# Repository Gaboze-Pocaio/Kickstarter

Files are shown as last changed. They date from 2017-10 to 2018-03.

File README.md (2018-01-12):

# Game Boy Zero

> Looking for a no frills multi system emulator that fits in your pocket? Look no further! This is it, Gameboy Zero - Handheld Edition!!!
>
> This project is a collaboration between  [moosepr](https://github.com/moosepr/) and  [32teeth](https://github.com/32teeth)
>
> We are **live** on [KickStarter](https://www.kickstarter.com/projects/sparky/gameboy-zero-handheld-edition)
>
> **Thank you everyone for your support.**





## Introduction

### Gameboy Zero - Handheld Edition
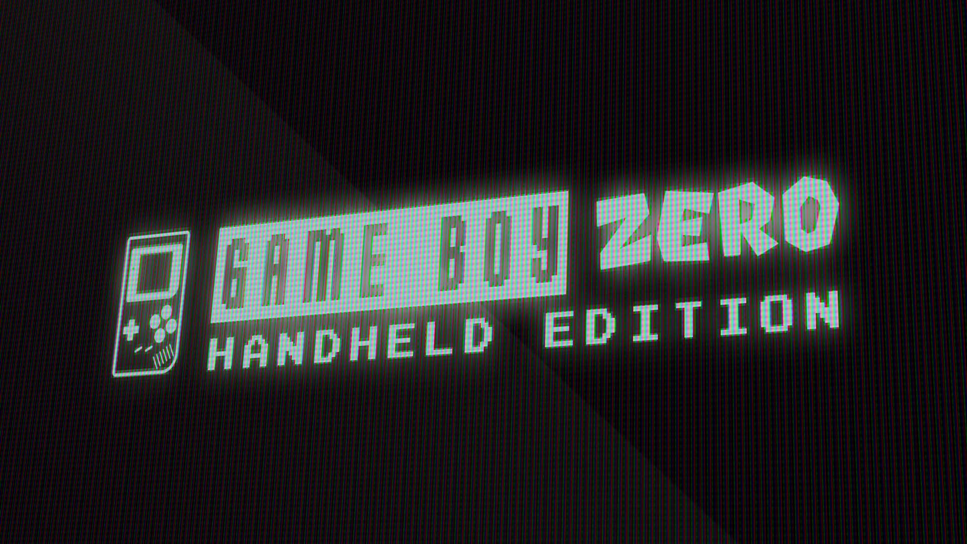
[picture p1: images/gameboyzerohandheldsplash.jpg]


Raspberry Pi Zero based arcade in you pocket

### Features:

* 2.8" TFT LCD
* Gameboy button layout interface
* Raspberry Pi Zero
* Battery Charger
* Shoulder / Trigger buttons
* 60 frames per second display

### Platforms:

The boards have been tested with the following platforms:

- [x] [Emulation Station](http://www.emulationstation.org/)
- [ ] [Lakka](http://www.lakka.tv/)
- [x] [RetroPie](https://retropie.org.uk/)

Other platforms are yet to be tested.

#### Eagle CAD Library

With our project we have included a few custom Eagle CAD Libraries

* [Displays](/library/GameboyZeroHandheldDisplays.lbr)
* [Raspberry Pi Zero](/library/RPI-Zero.lbr)

#### 3D Render
* [white board with parts](https://32teeth.github.io/Gameboy-Zero-Kickstarter/?parts)
* [black board no parts](https://32teeth.github.io/Gameboy-Zero-Kickstarter/?board)
* [holiday express no parts](https://32teeth.github.io/Gameboy-Zero-Kickstarter/?holiday)

## Details

| Version | Top | Bottom |
| --- | --- | --- |
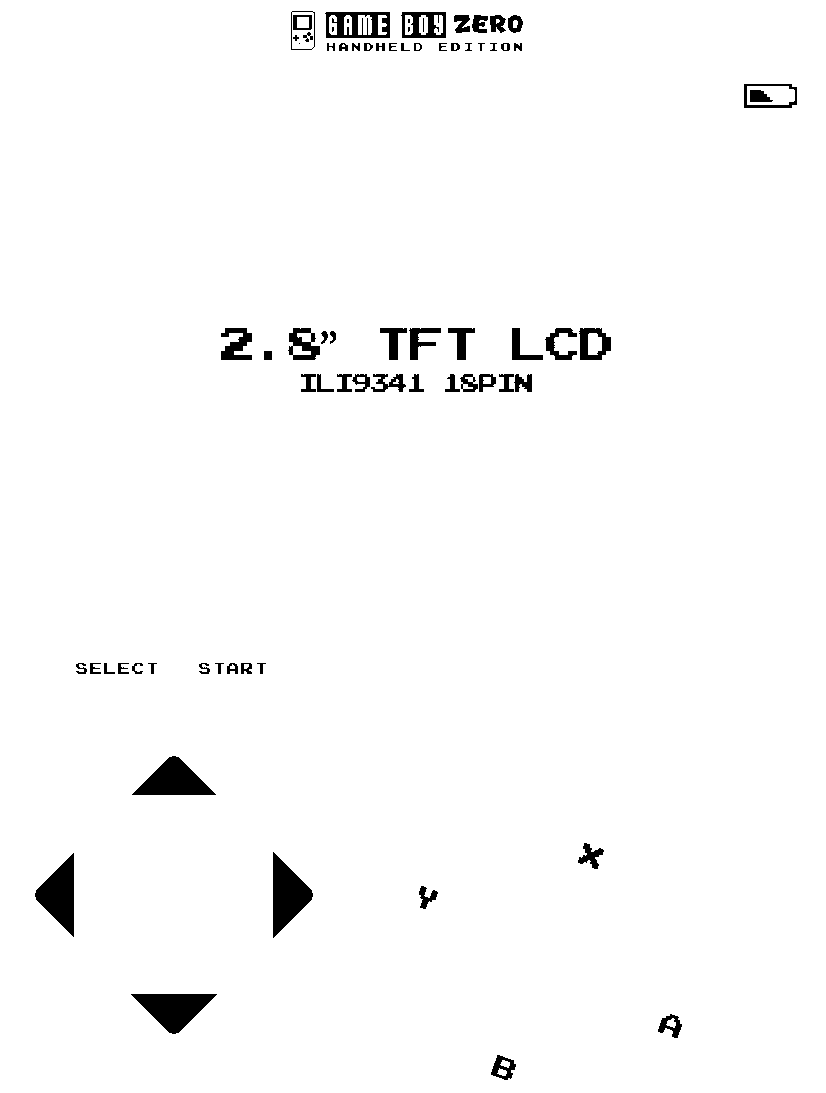
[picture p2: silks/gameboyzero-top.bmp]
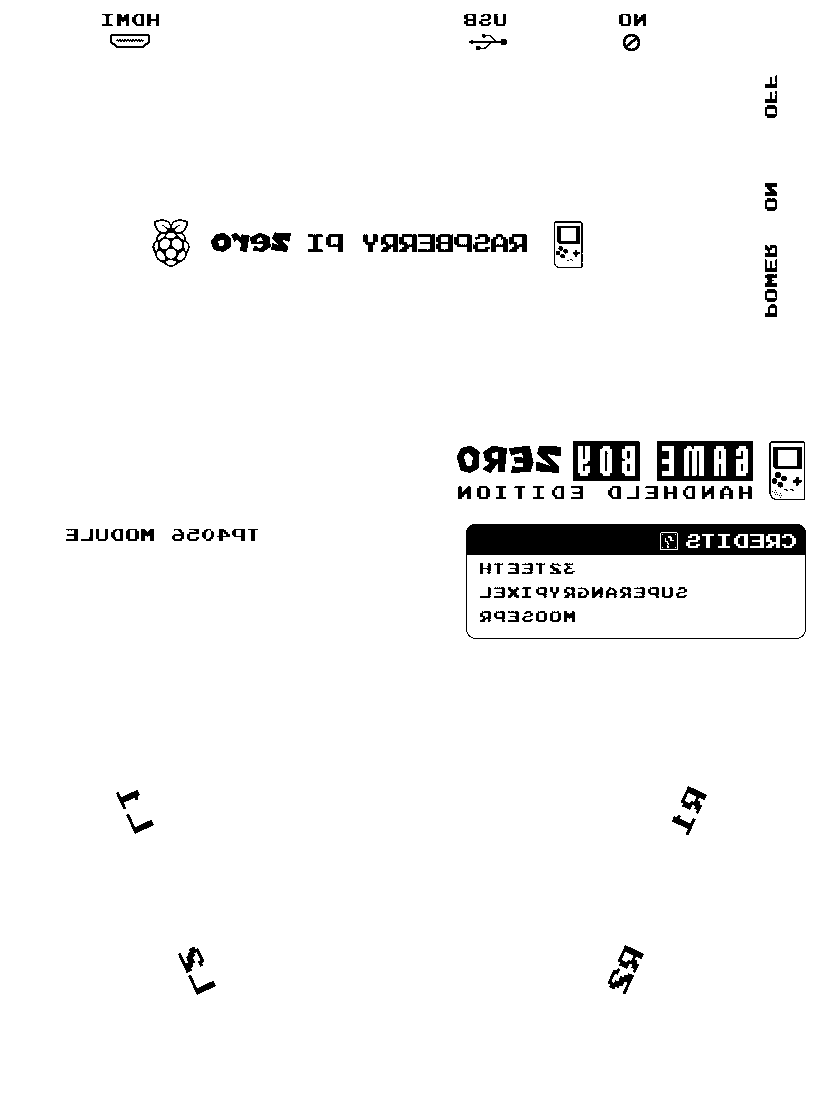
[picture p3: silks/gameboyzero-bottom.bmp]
| Flat Screen |  |  |
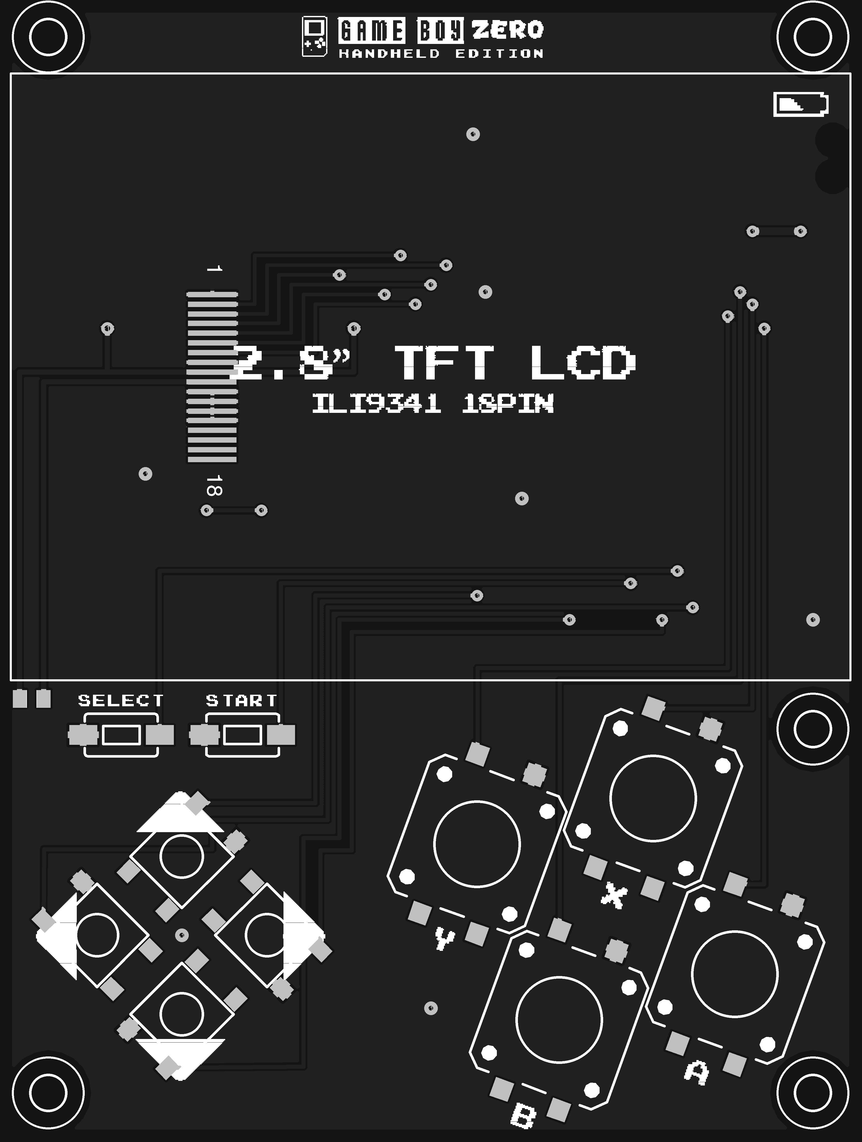
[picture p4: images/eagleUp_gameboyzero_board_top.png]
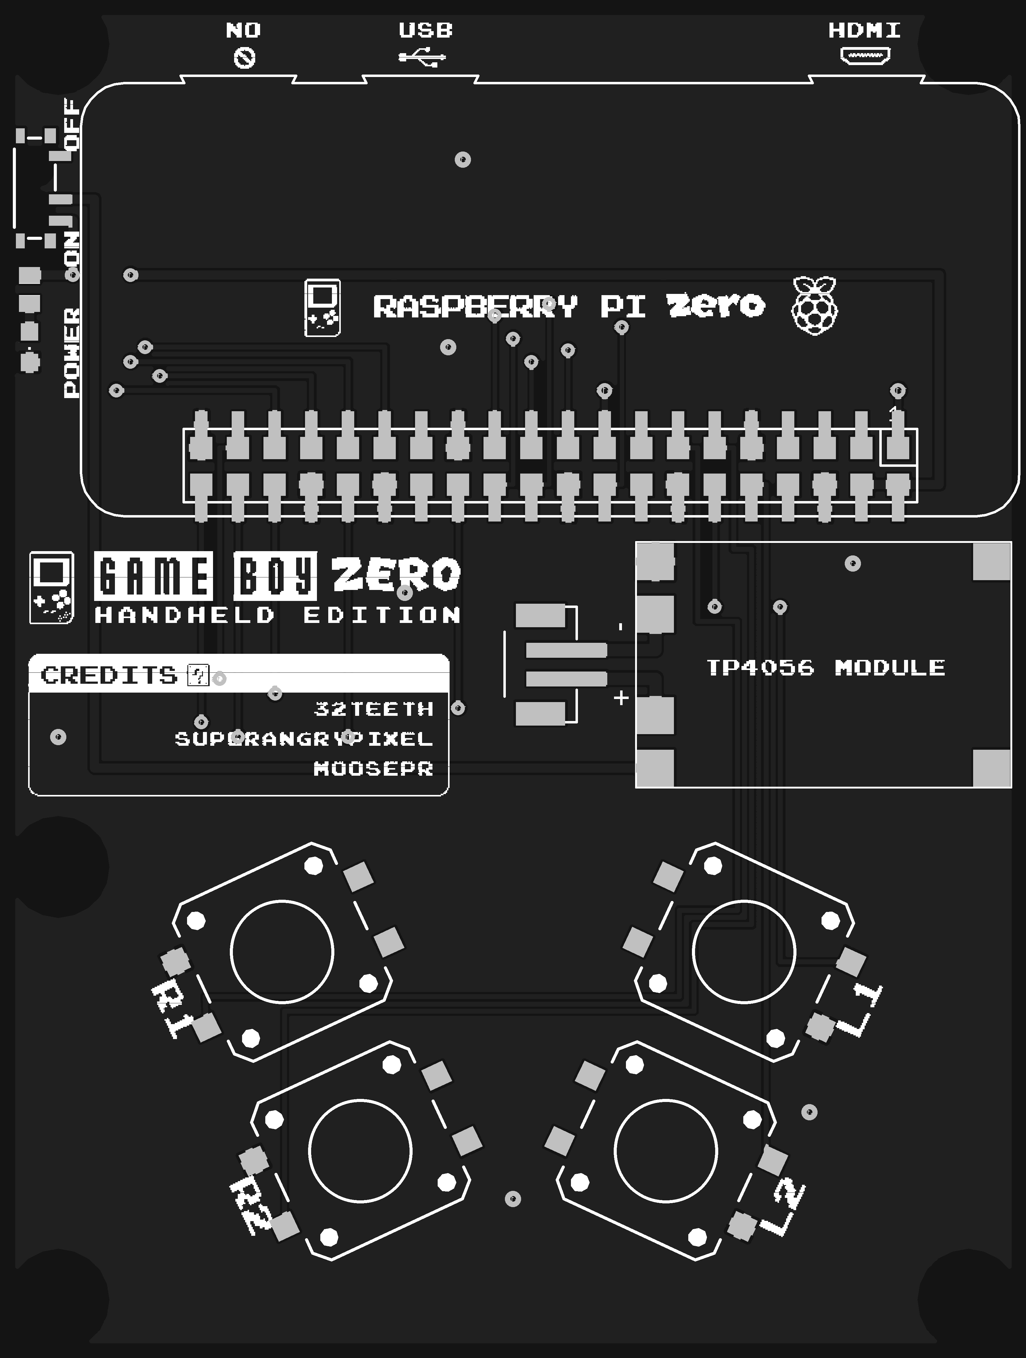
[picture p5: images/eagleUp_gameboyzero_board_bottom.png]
| Composite Board |  |  |
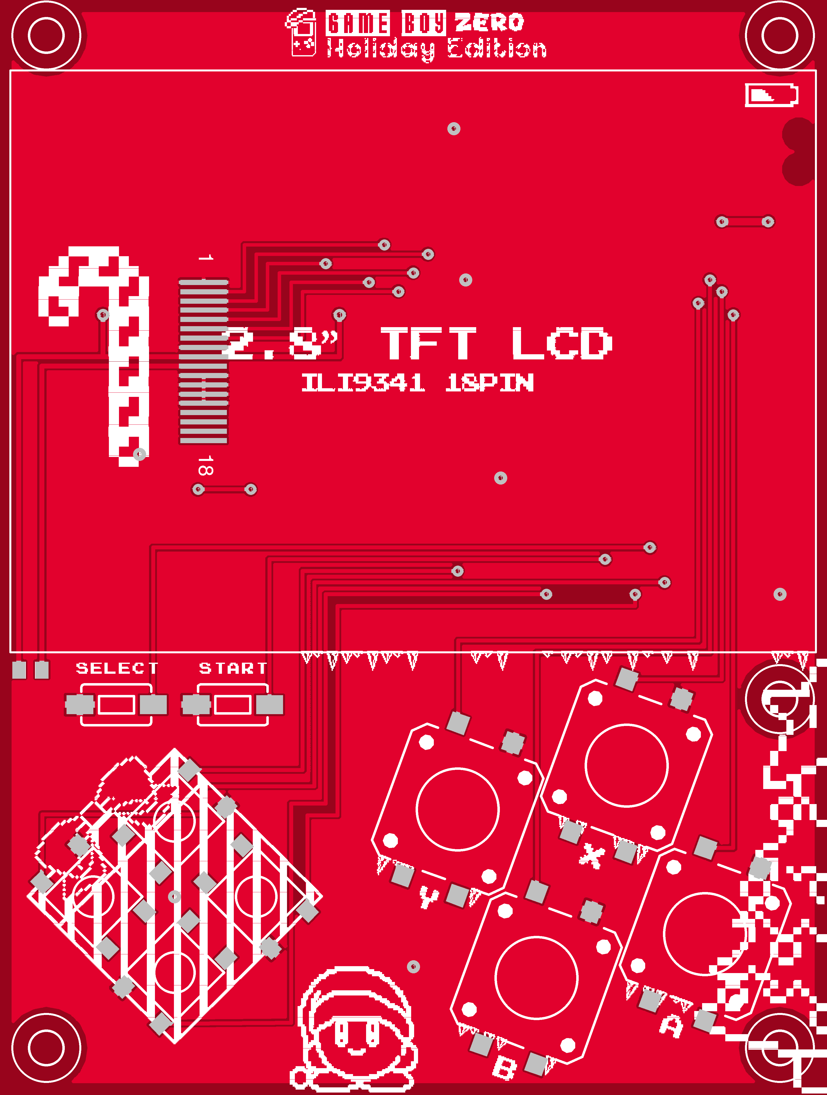
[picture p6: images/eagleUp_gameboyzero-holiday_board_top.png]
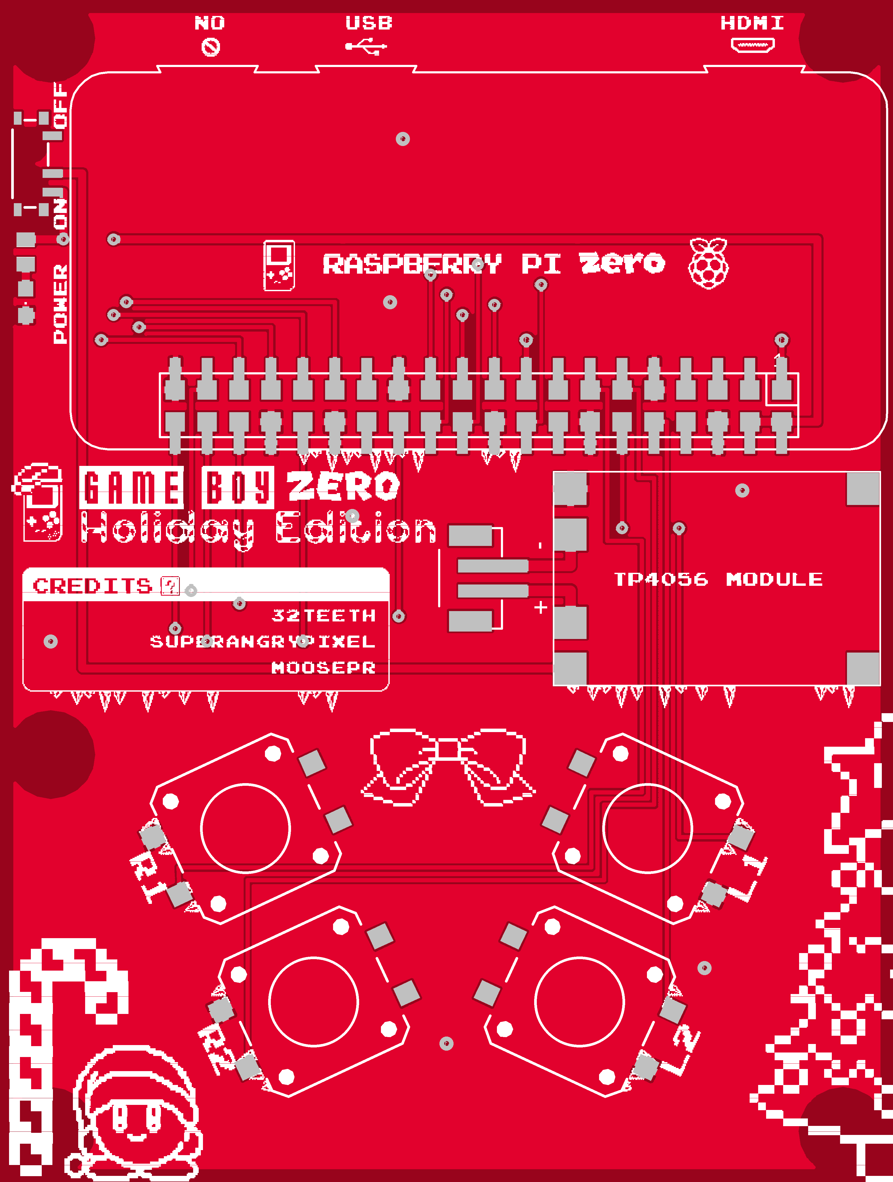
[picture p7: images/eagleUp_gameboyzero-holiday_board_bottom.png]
| Holiday Express Board |  |  |

## Custom Silk Screen

if you plan on changin the silk design,
* use the [gameboyzero sketch](design/gameboyzero) file
* all fonts required are in the  [fonts folder](fonts/)
* export artboard (with either 'TOP' or 'BOTTOM' group active as JPG)

*converting jpg to 2 color bitmap*
```shell
# imagemagick is required brew package
$ brew install imagemagick

# convert (replace with your file names and outputs)
# ex: convert "gameboyzero-top.jpg" -depth 1 -monochrome -colors 2 "gameboyzero-top.bmp"
$ convert "[jpg to convert]" -depth 1 -monochrome -colors 2 "[bmp to output]"
```

#### Import bmp in Eagle CAD.

* File > Import > Bitmap
* Select your bitmap
* Select **only** black color
* Change scale type to *mm*
* Change scale to ***0.086** (disregard the scale in the images)*
* Place it on layer layer 21 (tPlace) or 22 (bPlace)

| Top | Bottom |
| --- | --- |
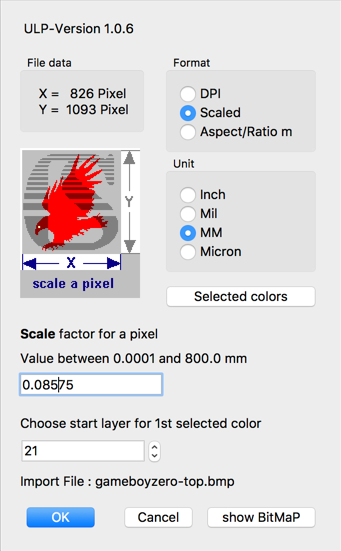
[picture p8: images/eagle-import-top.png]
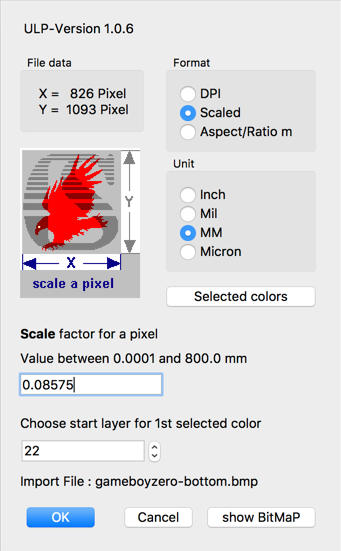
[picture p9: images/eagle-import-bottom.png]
|  |  |

## Plexi Case

The design for the layered plexi case are in the [case folder](/case)

*It consists of 5 layers:*
* TOP (optional for screen protection)
* SCREEN (fits over 2.8" TFT LCD)
* PI ZERO (fits around the Raspberry Pi Zero and TF4056 Module)
* BOTTOM (fits on top of the Raspberry Pi Zero)
* BATTERY (this is the layer to hold the LiPo battery in place)

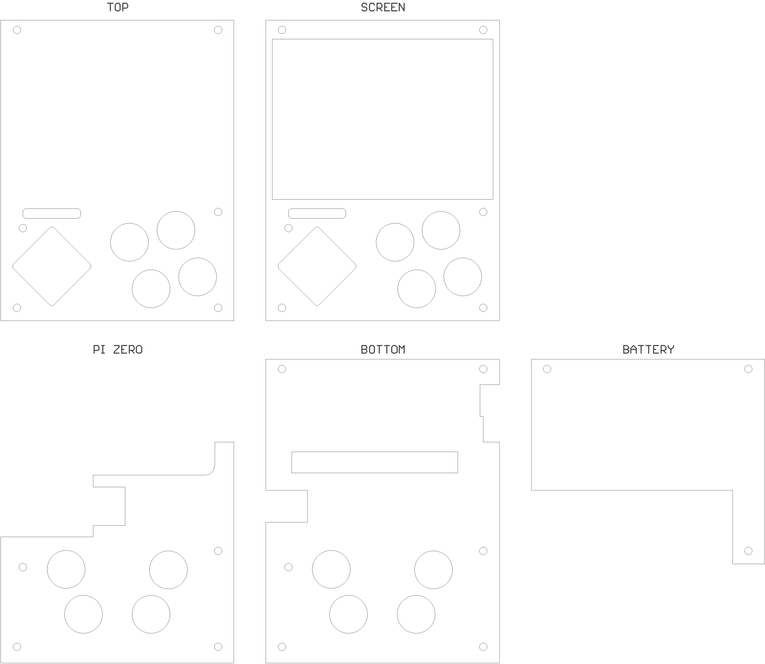
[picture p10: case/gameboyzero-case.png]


## Custom Config

> If you do not plan on using the provided Raspberry Pi image, simply [download](https://retropie.org.uk/download/) the latest RetroPie pre made image for the Raspberry Pi Zero

Once you have installed RetroPie onto your SD card and mounted it on your Pi follow along with the [Installation Instructions](INSTALL.md) document provided

#### A word from our sponsor

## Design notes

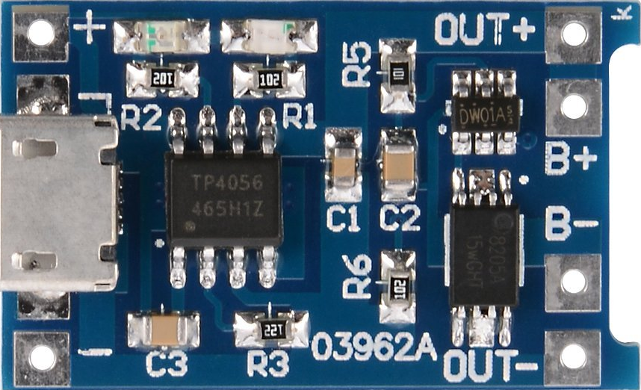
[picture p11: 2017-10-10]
docs/assets/gameboyzero-split-board/__auto_37.png

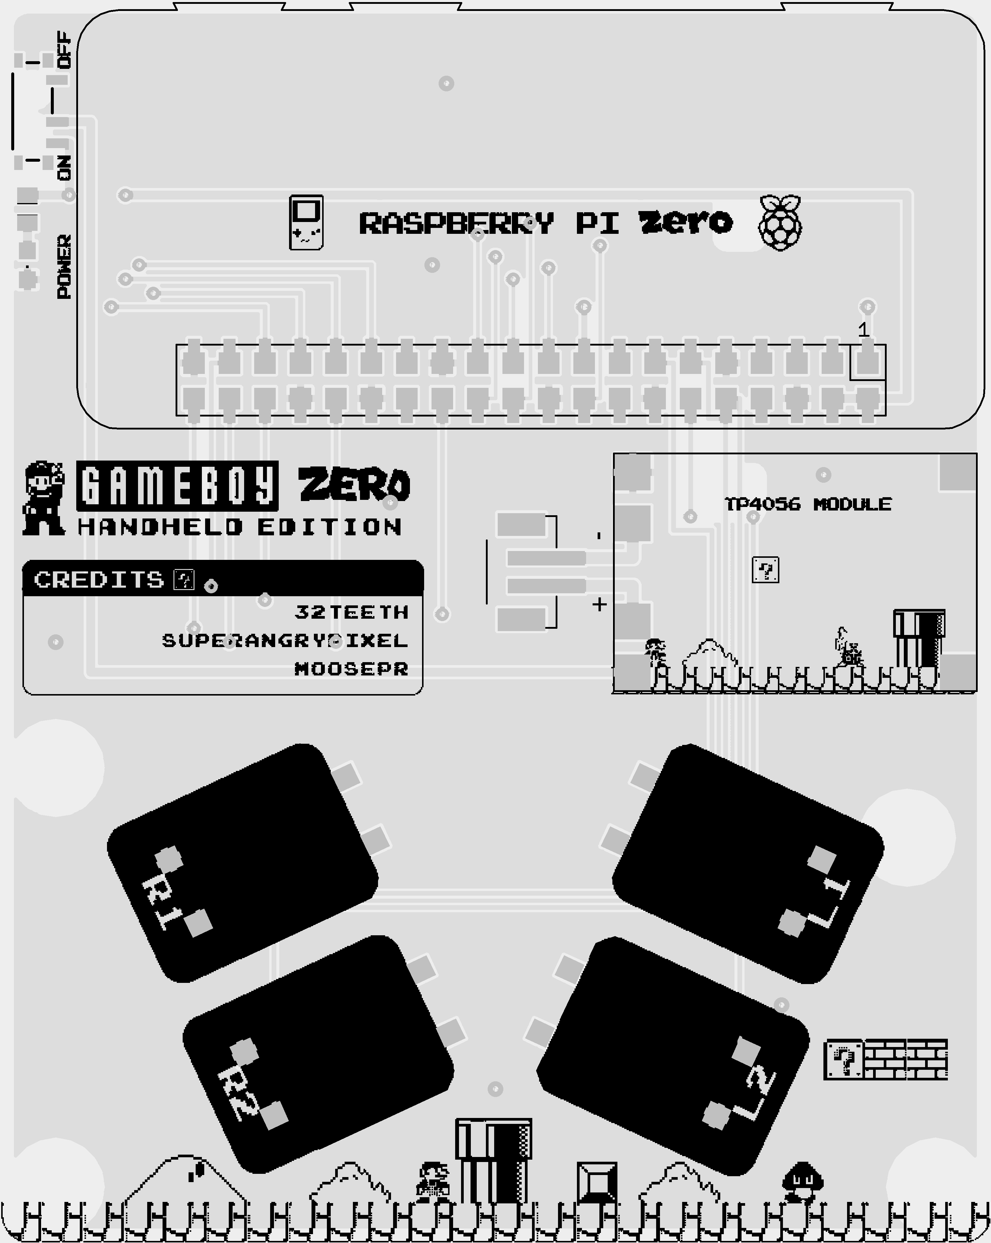
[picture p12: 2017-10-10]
docs/assets/gameboy/eagleUp_GBZH-2.8-JOY_bottom_board.png

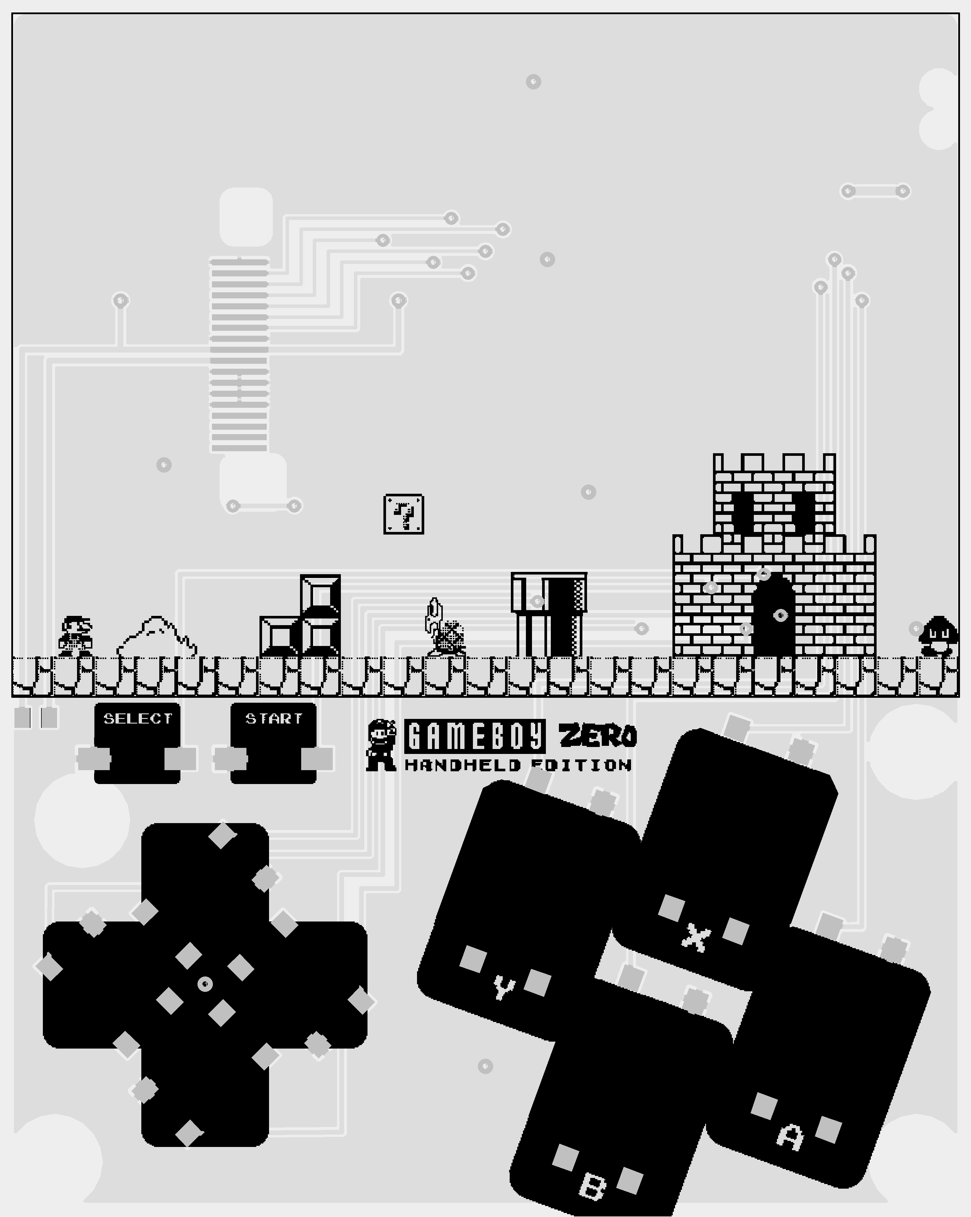
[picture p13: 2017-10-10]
docs/assets/gameboy/eagleUp_GBZH-2.8-JOY_top_board.png

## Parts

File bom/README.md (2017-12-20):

[Digi-Key Cart](http://www.digikey.com/short/qqrv9p)

**Not including** [TP4056 Charging Module](https://www.aliexpress.com/item/1-a-lithium-battery-charging-and-protect-one-plate-protection-2-in-1-18650-lithium-battery/1494965903.html) & [2.8" LCD Screen](https://www.aliexpress.com/item/2-8-inch-TFT-screen-4-wire-SPI-240-320-color-display-panel-ILI9341-drive-18/32797875095.html)

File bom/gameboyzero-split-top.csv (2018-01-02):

Designator | Manufacturer Part Number | Quantity
J2 | https://www.digikey.ca/product-detail/en/sullins-connector-solutions/PEC06SAAN/S1012E-06-ND/859159 | 1
CN1 | https://www.digikey.ca/product-detail/en/jst-sales-america-inc/S2B-PH-SM4-TB(LF)(SN)/455-1749-1-ND/926846 | 1
LED1 | https://www.digikey.ca/product-detail/en/lite-on-inc/LTST-C191KRKT/160-1447-1-ND/386836 | 1
S2 | https://www.digikey.ca/product-detail/en/apem-inc/MA12RTR/679-1847-1-ND/1973774 | 1
R1 | https://www.digikey.ca/product-detail/en/stackpole-electronics-inc/RMCF0805FT3R90/RMCF0805FT3R90CT-ND/2418397 | 1
R2 | https://www.digikey.ca/product-detail/en/yageo/RC0805JR-071KL/311-1.0KARCT-ND/731165 | 1
SCREEN1 | https://www.aliexpress.com/item/2-8-inch-TFT-screen-4-wire-SPI-240-320-color-display-panel-ILI9341-drive-18/32843525653.html | 1
BTN_A, BTN_B, BTN_X, BTN_Y | https://www.digikey.ca/product-detail/en/e-switch/TL3300DF160Q/EG4906CT-ND/2498468 | 4
BTN_SELECT, BTN_START | https://www.digikey.ca/product-detail/en/cts-electrocomponents/222BMVBAR/CT3090CT-ND/5227996 | 2
BTN_DOWN, BTN_LEFT, BTN_RIGHT, BTN_UP | https://www.digikey.ca/product-detail/en/c-k/PTS645SM43SMTR92-LFS/CKN9112CT-ND/1146934 | 4
POWER1 | https://www.aliexpress.com/item/1-a-lithium-battery-charging-and-protect-one-plate-protection-2-in-1-18650-lithium-battery/1494965903.html | 1
PI1 | https://www.digikey.ca/product-detail/en/Amphenol+FCI/95157-440LF/609-3124-ND/1824561 | 1

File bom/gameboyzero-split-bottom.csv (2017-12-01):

Designator | Manufacturer Part Number | Quantity
J3 | https://www.digikey.ca/product-detail/en/sullins-connector-solutions/PPTC061LFBN-RC/S7004-ND/810145 | 1
LED2 | https://www.digikey.ca/product-detail/en/lite-on-inc/LTST-C191KRKT/160-1447-1-ND/386836 | 1
R3 | https://www.digikey.ca/product-detail/en/yageo/RC0805JR-071KL/311-1.0KARCT-ND/731165 | 1
BTN_L1, BTN_L2, BTN_R1, BTN_R2 | https://www.digikey.ca/product-detail/en/e-switch/TL3300DF160Q/EG4906CT-ND/2498468 | 4

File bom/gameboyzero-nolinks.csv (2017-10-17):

Designator | Manufacturer Part Number | Quantity
CN1 | S2B-PH-SM4-TB(LF)(SN) | 1
LED1 | LTST-C191KRKT | 1
S2 | MA12R | 1
R1, R2 | RMCF0805JT100R | 2
SCREEN1 | see link for screen | 1
BTN_A, BTN_B, BTN_L1, BTN_L2, BTN_R1, BTN_R2, BTN_X, BTN_Y | TL3300AF160Q | 8
BTN_SELECT, BTN_START | 222BMVBAR | 2
BTN_DOWN, BTN_LEFT, BTN_RIGHT, BTN_UP | TL3301SPF160QG | 4
POWER1 | see link for power | 1
PI1 | see link for smd header | 1

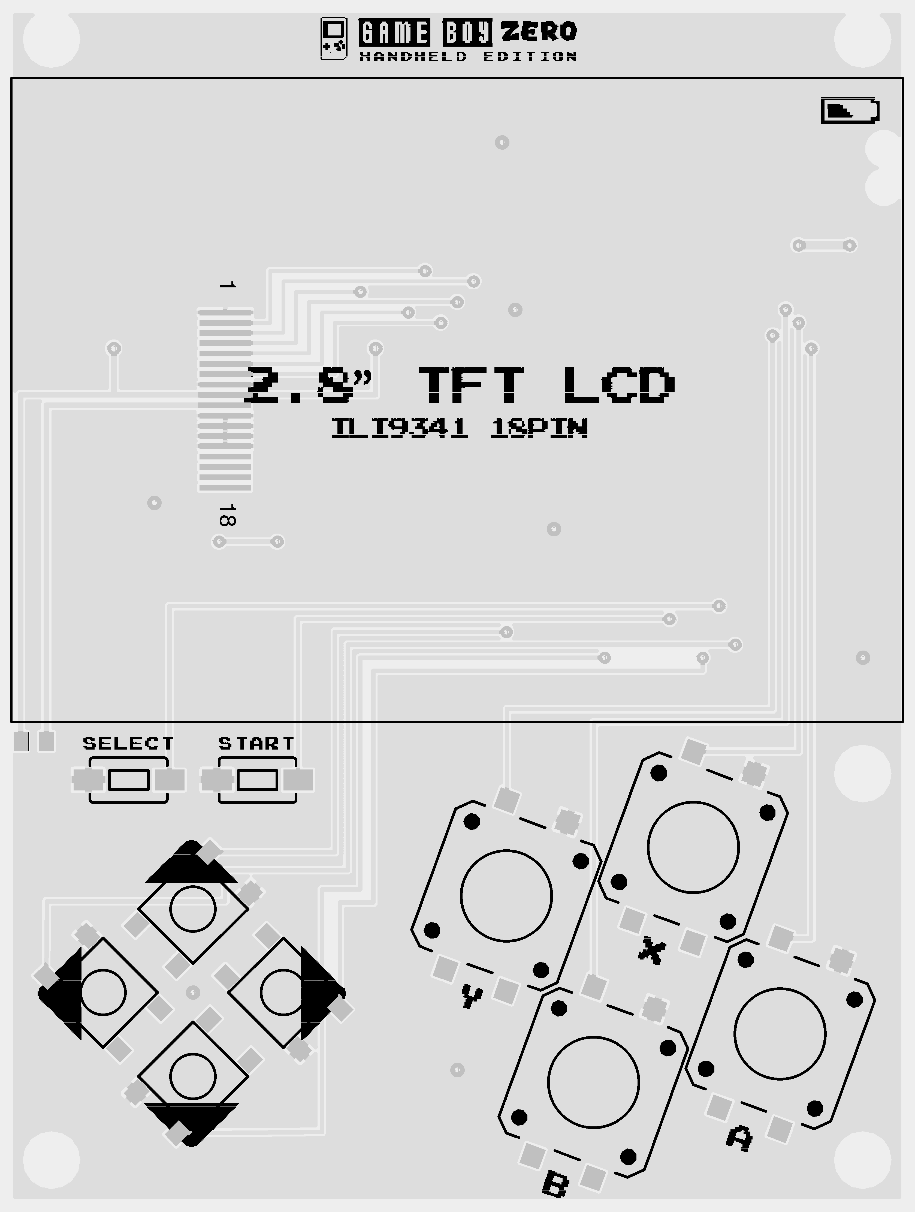
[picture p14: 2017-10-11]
docs/assets/gameboy-parts/eagleUp_gameboyzero_top_board.png

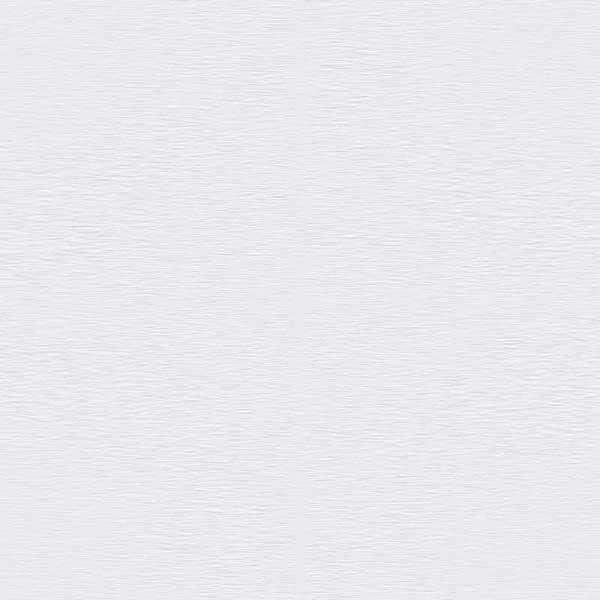
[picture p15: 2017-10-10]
docs/assets/gameboy-parts/Metal_Silver.jpg

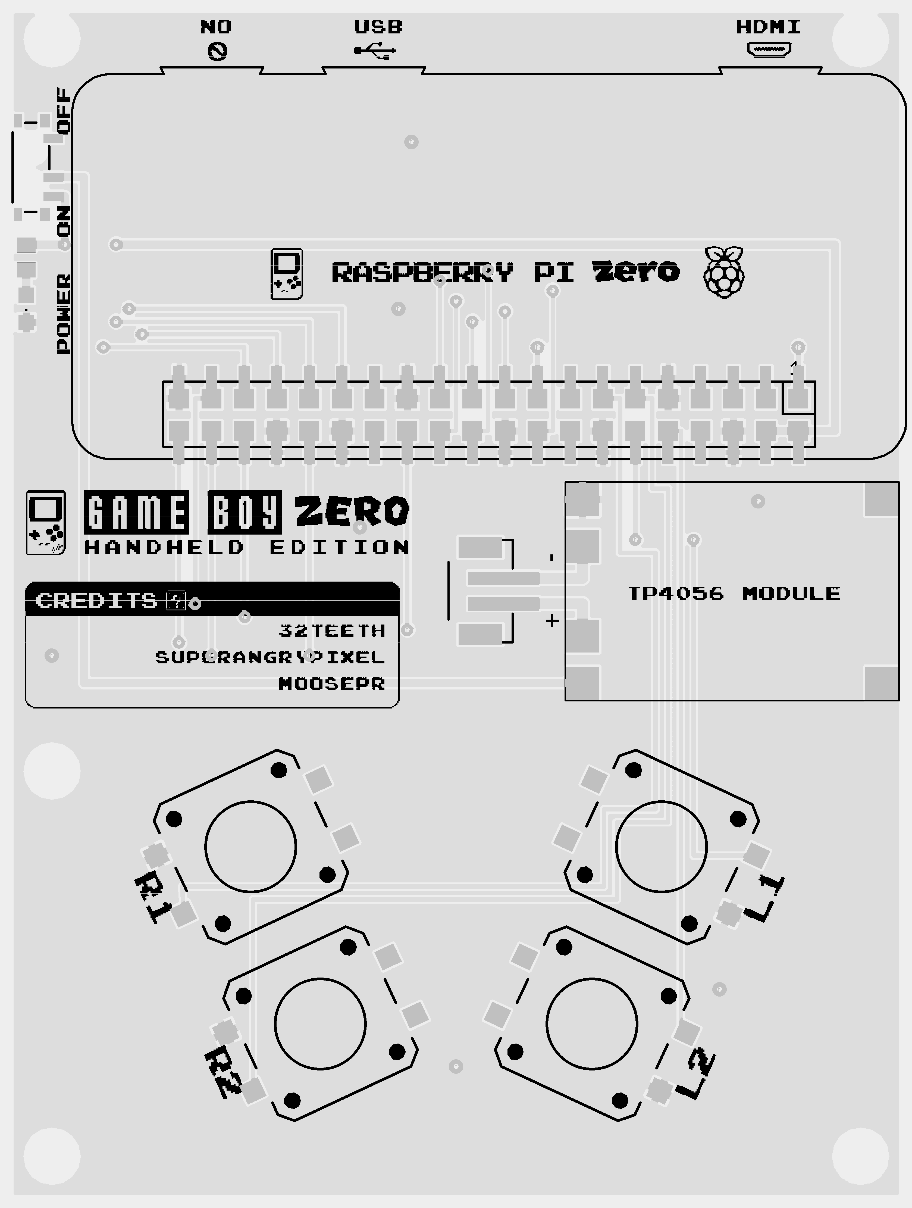
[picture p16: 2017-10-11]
docs/assets/gameboy-parts/eagleUp_gameboyzero_bottom_board.png

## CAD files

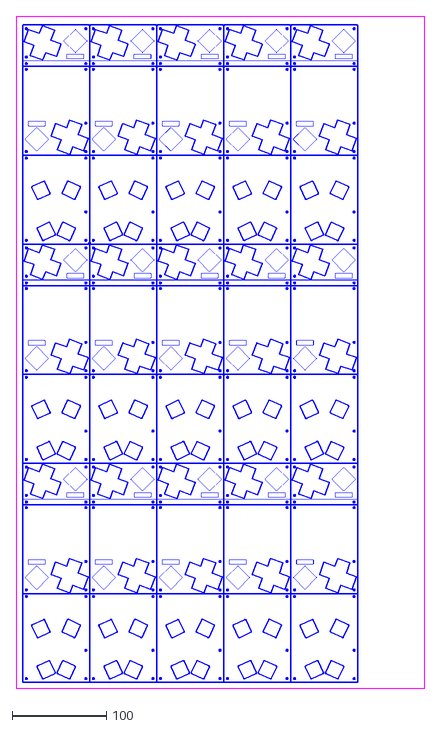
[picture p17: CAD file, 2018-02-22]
case/gameboyzero-split-board/gameboyzero-split-board-single.dxf
432.1 x 711.5

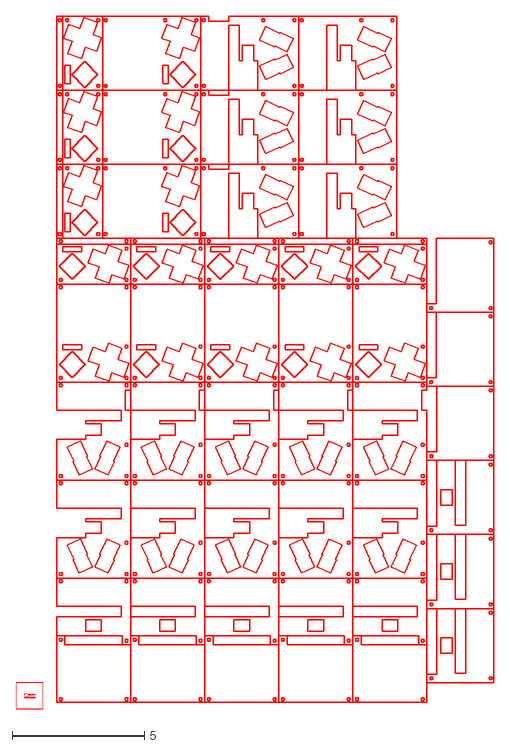
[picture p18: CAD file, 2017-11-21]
case/gameboyzero/gameboyzero.dxf
18.0 x 26.2

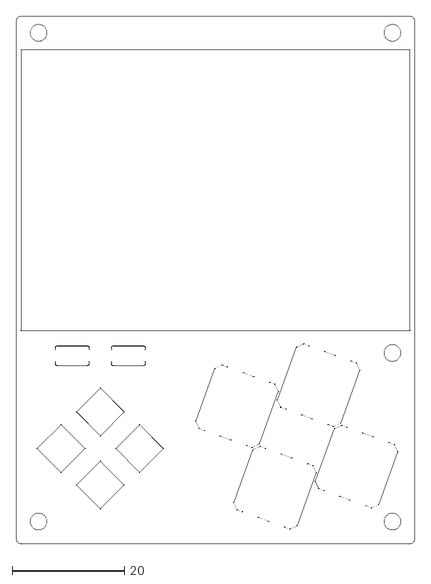
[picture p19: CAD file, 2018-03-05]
eagle/gameboyzero-split-board/gameboyzero-split-top.dxf
71.0 x 94.0

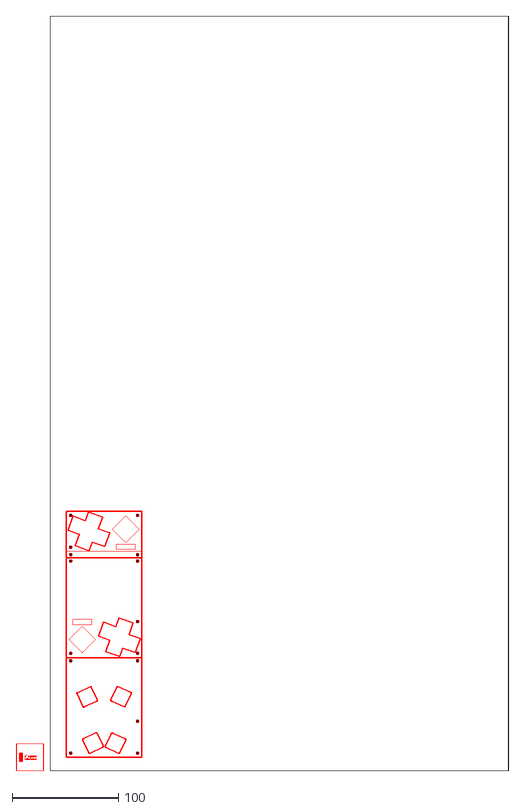
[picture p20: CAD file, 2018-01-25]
case/gameboyzero-split-board/gameboyzero-split-board.dxf
463.7 x 711.4

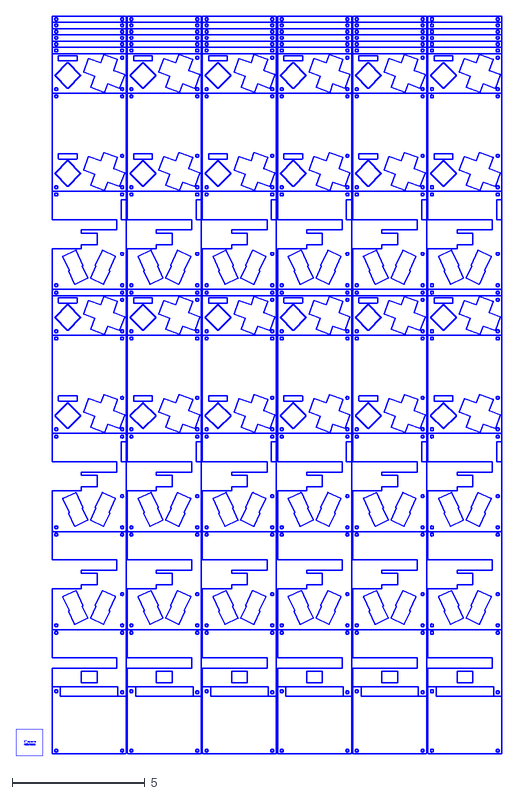
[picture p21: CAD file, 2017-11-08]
case/gameboyzero/gameboyzero-blue.dxf
18.3 x 27.9

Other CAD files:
sketchup/gameboyzero-holiday.skp
sketchup/gameboyzero-split-board.skp
sketchup/gameboyzero-split-board~.skp
sketchup/gameboyzero.skp

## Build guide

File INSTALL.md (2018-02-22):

# Gameboy Zero - Handheld Edition Installation

> This document is intended for a somewhat advanced user base, but we have made it simple enough to follow along for anyone

### Prerequisites

1. Fresh RetroPie install mounted on an SD Card
2. Raspberry Pi Zero *(preferably WiFi edition)*
3. Keyboard
4. OTG USB Cable (to plug in a USB A type keyboard)
5. Mini HDMI (you know, to see things on a screen)

## Step 1

> Setup Raspberry Pi requirements

With your Keyboard and HDMI cable plugged in, go ahead and turn on your Raspberry Pi Zero
Allow it to go through the boot requirements (RetroPie will reboot once on it's own)

Once the Raspberry Pi boots into RetroPie, it will start EmulationStation automatically.

You will see a screen telling you to either set up a controller or press F4 to exit.

* Press F4 to exit to terminal

### WiFi

Once the Raspberry Pi reboots into EmulationStation, use your keyboard and navigate to RetroPie configuration

Select WiFi and enter your SSID/PSK information as necessary

Once you have connected to your WiFi network, you can go back to your laptop and continue via SSH from there

#### Optional

Should you choose to work completely from terminal, hit F4 from the EmulationStation menu to get to terminal

```shell
sudo iwlist wlan0 scan
sudo nano /etc/wpa_supplicant/wpa_supplicant.conf
```

```shell
network={
  ssid="your ssid"
  psk="your password"
}
```

```shell
sudo systemctl daemon-reload
ifconfig wlan0
```

If you have done your WiFi correctly from here you can use SSH

```
ssh pi@[ip address]
```

### Config

* Run the Rapsberry Pi configuration program
```shell
sudo raspi-config
```
In the Interfaceing Options menu, you will need to 
1. Enable SSH
2. Enable SPI

In the Advance Options menu, you will need to
1. Expand Filesystem
2. Disable Overscan

Once these are complete, you will be asked to reboot you Raspbery Pi.
Do so.

## Step 2

> We will now be connecting the 2.8" ILI9341 TFT LCD module, so you can set your other keyboard aside for now

From you computer *(not the Raspberry Pi)*

### TFT Device

Enter the following to add a Loadable Kernel Module for the TFT Device
```shell
sudo modprobe fbtft_device custom name=fb_ili9341 gpios=reset:25,dc:24 speed=80000000 fps=60 bgr=1 rotate=90
```

Confirm the module has been loaded

```shell
dmesg | tail 
```

See the TFT LCD module details
```shell
fbset -fb /dev/fb1
```

Lets test that we can show 'stuff' on the TFT LCD module (this will simply add static noise)
```shell
cat /dev/urandom > /dev/fb1
```

Map the console to the TFT LCD Module
*you should now see a scaled terminal window on the TFT*
```shell
con2fbmap 1 1
```

Should you ever need to stop the mapping, reverse the command
```shell
# switch tft to hdmi
con2fbmap 1 0
```

*Note:* if you need to remove the module, simply

```shell
sudo modprobe -r fbtft_device
```

## Step 3

### Automate the above on startup

Open the modules file
```shell
sudo nano /etc/modules
```

Add these lines to the bottom
```shell
spi-bcm2835
fbtft_device
```

*Hit 'CTRL+X' and 'Y' to confirm the save*

### Create a configuration file for the TFT LCD Module

This will create an empty file named fbtft.conf
```shell
sudo nano /etc/modprobe.d/fbtft.conf
```

Add this line to the empty file
```shell
options fbtft_device custom name=fb_ili9341 gpios=reset:25,dc:24 speed=80000000 fps=60 bgr=1 rotate=90 custom=1
```

*Hit 'CTRL+X' and 'Y' to confirm the save*

### Installing the Framebuffer Copy tool

The following lines will download and install the Frambuffer Copy tool in a folder in the root directory

```shell
cd
sudo apt-get install cmake
git clone https://github.com/tasanakorn/rpi-fbcp fbcp
cd fbcp/
mkdir build
cd build/
cmake ..
make
sudo install fbcp /usr/local/bin/fbcp
fbcp
```

*Hit CTRL+C to exit 'fbcp'*

### Add Framebuffer Copy to our boot sequence
In order to have a command or program run when the Pi boots we will edit the 'rc.local' file

```shell
sudo nano /etc/rc.local
```

Add the following **just before** the ```exit 0``` line
```shell
fbcp&
```

*Hit 'CTRL+X' and 'Y' to confirm the save*

Your file *(if you have no other commands running)* will look something like this
```shell
### replace with this
_IP=$(hostname -I) || true
if [ "$_IP" ]; then
  printf "My IP address is %s\n" "$_IP"
fi

fbcp&

exit 0
```

## Step 5

> USB Audio Configuration

Plug in your USB Audio Card, and list your usb devices

```shell
lsusb
```

Now run the sound modules probe

```shell
cat /proc/asound/modules
```

You will see something like

```shell
 0 snd_bcm2835
 1 snd_usb_audio
```

The ```snd_bcm2835``` is the default, we wan't to force the USB output so, we will edit the conf file

```shell
sudo nano /etc/modprobe.d/alsa-base.conf
```

Add these lines

```shell
options snd_usb_audio index=0
options snd_bcm2835 index=1
options snd slots=snd-usb-audio,snd-bcm2835
```

Reboot, and return to terminal (F4) once EmulationStation has restarted

List out the module probe

```
cat /proc/asound/modules
```

You will see something like

```shell
 0 snd_usb_audio
 1 snd_bcm2835
```

Success, enjoy the sound

## Step 6

> Now we are ready to configure the GPIO on the Raspberry Pi as a controller

### Install RetroGame

```shell
cd
curl -O https://raw.githubusercontent.com/adafruit/Raspberry-Pi-Installer-Scripts/master/retrogame.sh
sudo bash retrogame.sh
```
When you run the retrogame.sh file, you will be presented with a menu.

Select the **PiGRRL 2 Controls** option, and the program will continue to install some modules.

Once complete, you will be asked if you want to reboot. 
#### Don't reboot just yet

## Step 7
> You will now be assigning keyboard inputs to action buttons of the controller (GPIO pins on the Raspberry Pi)

### RetroGame Configuration

Edit the RetroGame configuration file
```shell
sudo nano /boot/retrogame.cfg
```

You can replace the entire file with the following
* **pro tip**:Hit CTRL+K on you keyboard to delete lines*

```shell
# Here's a pin configuration for the PiGRRL 2 project:
LEFT      		22  # Joypad left
RIGHT     		20  # Joypad right
UP         		 7  # Joypad up
DOWN      		12  # Joypad down
LEFTCTRL  		19  # 'A' button
LEFTALT    		 5  # 'B' button
Z          		 6  # 'X' button
X         		13  # 'Y' button
RIGHTSHIFT      26  # 'Select' button
ENTER     		16  # 'Start' button
A         		18  # Left shoulder button
S         		27  # Right shoulder button
Q         		15  # Left trigger button
W         		17  # Right trigger button
ESC       		16 26  # Exit ROM; PiTFT Button 1
```

*Hit 'CTRL+X' and 'Y' to confirm the save*

### EmulationStation Input Configuration
> This is really just a visual check to ensure your file looks as below

Open the EmulationStation Input configuration file
```shell
sudo nano ~/.emulationstation/es_input.cfg
```

Ensure that your file's content are **exactly** as below
```xml
<?xml version="1.0"?>
<inputList>
  <inputAction type="onfinish">
    <command>/opt/retropie/supplementary/emulationstation/scripts/inputconfiguration.sh</command>
  </inputAction>
  <inputConfig type="keyboard" deviceName="Keyboard" deviceGUID="-1">
    <input name="pageup" type="key" id="97" value="1"/>
    <input name="start" type="key" id="13" value="1"/>
    <input name="up" type="key" id="1073741906" value="1"/>
    <input name="a" type="key" id="1073742048" value="1"/>
    <input name="b" type="key" id="1073742050" value="1"/>
    <input name="down" type="key" id="1073741905" value="1"/>
    <input name="pagedown" type="key" id="115" value="1"/>
    <input name="right" type="key" id="1073741903" value="1"/>
    <input name="x" type="key" id="122" value="1"/>
    <input name="select" type="key" id="1073742053" value="1"/>
    <input name="y" type="key" id="120" value="1"/>
    <input name="left" type="key" id="1073741904" value="1"/>
  </inputConfig>
</inputList>
```

If all is good as above, hit CTRL+X to exit the editor and

# Step 8
> The final reboot, you can now unplug the HDMI from the Raspberry Pi

```shell
sudo nano /boot/cmdline.txt
```

```shell
dwc_otg.lpm_enable=0 console=tty1 console=ttyAMA0,115200 root=/dev/mmcblk0p2 rootfstype=ext4 elevator=deadline rootwait fbcon=map:10 fbcon=font:6x12 logo.nologo
```

Reboot
```shell
sudo reboot now
```

RetroPie will reboot and start EmulationStation *(all on the tiny screen)*

Once EmulationStation is up, you will again see the 'No Device Configured' screen...  ...***Don't Panic***

With your keyboard plugged in, press and hold 'Enter' until the Controller Configuration shows up on the screen

Hit your keys on your keyboard as mapped above, skip the analog sticks
* **pro tip**: When you get to the section*

# Step 9
> This one is all on you

We **DO NOT** provide any system or game *'roms'*, for that you will need Google.

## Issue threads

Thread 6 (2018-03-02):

[3D Models] what's in the sketchup files ?

tobozo, 2018-03-02:
[EDIT] Found the 3D Models on a related repo although those seems to be for another model
- [Gameboy.stl](https://github.com/GameboyZero/GabozePocaio/blob/29c8e6133e9ad878d548ccbc102e7fb717bc6881/stl/Gameboy.stl)
- [GBPZ-top.stl](https://github.com/GameboyZero/GabozePocaio/blob/29c8e6133e9ad878d548ccbc102e7fb717bc6881/stl/GBPZ-top.stl)
- [GBPZ-bottom.stl](https://github.com/GameboyZero/GabozePocaio/blob/29c8e6133e9ad878d548ccbc102e7fb717bc6881/stl/GBPZ-bottom.stl)

got mine today from tindie \o/ unboxing went well and I was [looking for some 3d models](https://www.thingiverse.com/search?q=gameboy+zero) to print a Gameboy Zero case /w buttons, but it looks like the "Gameboy Zero" platform name is kinda generic and over used on thingiverse :sob:

I'm not sure if this is the right place to ask for this (already asked on tindie), but would any owner of a sketchup licence be kind enough to export the [sketchup files](https://github.com/32teeth/Gameboy-Zero-Kickstarter/tree/master/sketchup) into the non-proprietary STL format so github can display previews of what's in there?

https://extensions.sketchup.com/content/sketchup-stl

So far the [Blender importer](https://github.com/martijnberger/pyslapi) is the only solution I've found that doesn't require registration, but it requires versions of python and blender I don't use currently and can't upgrade without breaking my own scripts.

@32teeth if you're the lucky sketchup licence owner and author of these files, could you point me in the right direction, or eventually create a STL folder in this repo and populate it with the converted STL files?

tobozo, 2020-06-22:
closed by error or just not worth the answer?

Closed 2020-06-22.

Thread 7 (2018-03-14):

Back PCB can't mount to front if female headers are added to Pi Zero

albill, 2018-03-14:
If you put female headers on the underside of the Pi Zero (as the video shows as one of two options), the headers are so tall that they keep the back 4 button PCB from mating with its pins on the front PCB as the female headers make the distance too much.

tobozo, 2018-03-23:
you can still try this [workaround](https://twitter.com/TobozoTagada/status/970712510717419522)

32teeth, 2018-03-27:
Additionally you can use [Short Headers](https://www.adafruit.com/product/2243)

albill, 2018-04-06:
No, short headers turn out not to work (thought they're stuck on my zero now). The header pins that come pre-soldered are too long so even with short female headers, a mm or two of pin shows and the zero is moved far enough out that the two PCBs cannot be assembled flush.

My next step will be to gently trim a mm or two of of EACH pin, which is damn tedious when this all could have been avoided.

Did anyone even test this with headers before sending it out to Kickstarter backers or did you just test this by soldering the zero directly to the board?

tobozo, 2018-04-06:
Found this out too, now I've officially wasted two Pi Zeros by just attempting to replicate the mounting on the advertised product page, or by following @32teeth advices.

Closed 2020-06-22.

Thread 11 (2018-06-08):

Case .dxf files

mackemint, 2018-06-08:
Opening any of the .dxf-files under /case in Autodesk gives me the following error:
TranslationWorker-InternalFailure Unrecoverable exit code from extractor: -1073741831
AutoCAD-InvalidFile Sorry, the drawing file is invalid and cannot be viewed. - Please try to recover the file in AutoCAD, and upload it again to view.

Using other services produces similar error messages.

Closed 2020-06-22.

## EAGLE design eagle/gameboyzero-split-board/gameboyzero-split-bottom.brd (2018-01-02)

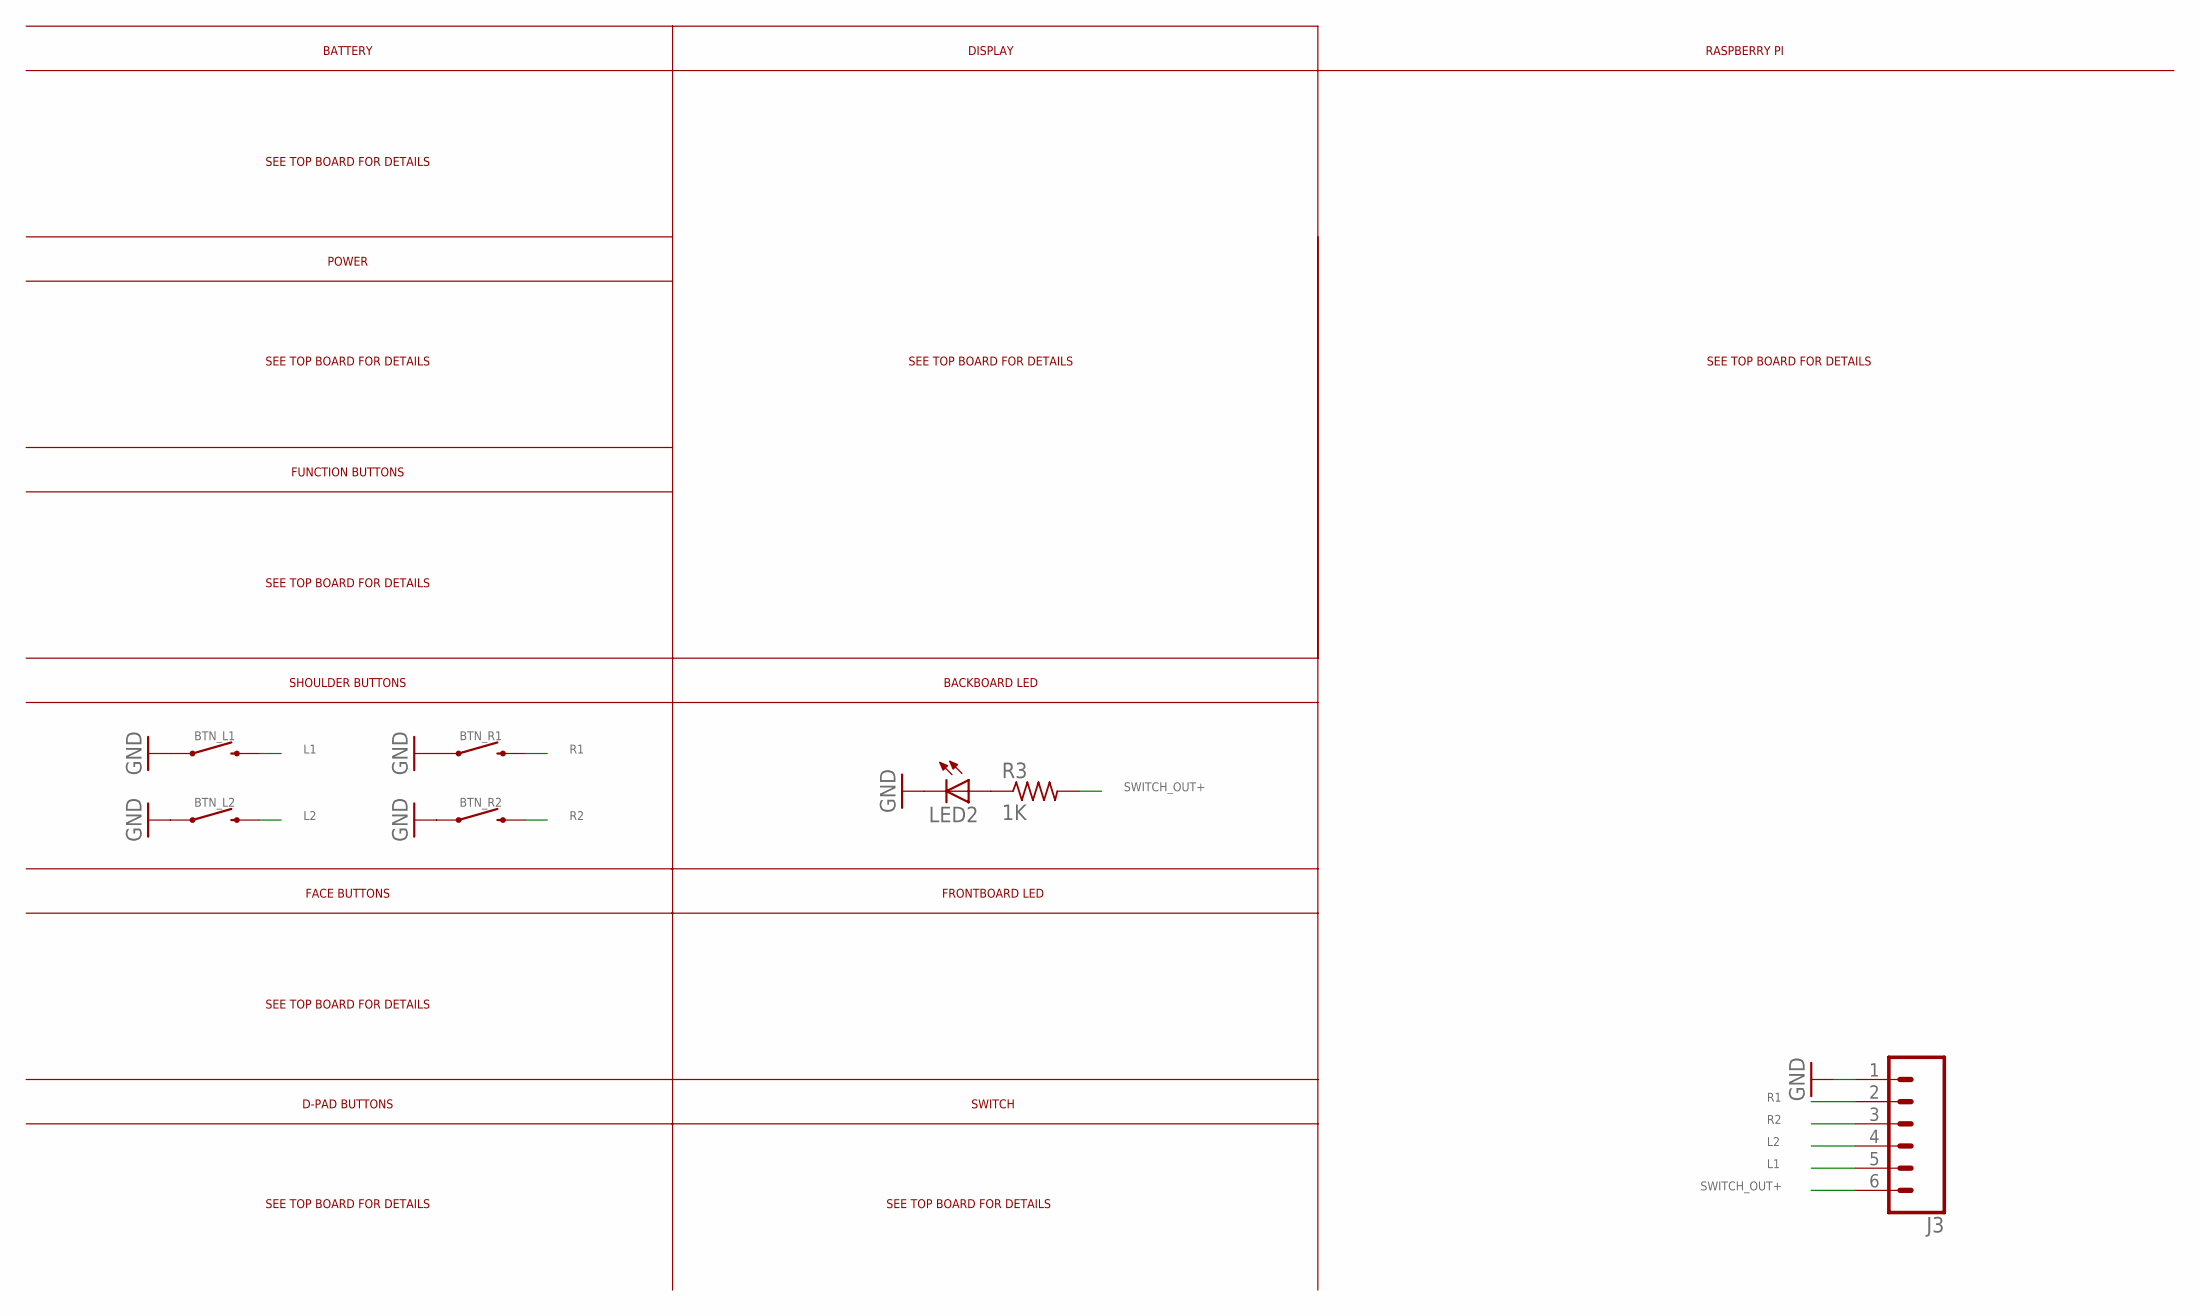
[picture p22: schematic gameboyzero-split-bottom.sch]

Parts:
BTN_L1, BTN_L2: MOMENTARY-SWITCH-SPST-SMD-12MM; TACTILE_SWITCH_SMD_12MM
BTN_R1, BTN_R2: MOMENTARY-SWITCH-SPST-SMD-12MM; TACTILE_SWITCH_SMD_12MM
J3: CONN_06SILK_FEMALE_PTH; 1X06
LED2: LEDCHIPLED_0805; CHIPLED_0805
R3: 1K; R0805

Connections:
GND: BTN_L1.1, BTN_L2.1, BTN_R1.1, BTN_R2.1, J3.1, LED2.C
L1: BTN_L1.3 (2), J3.5
L2: BTN_L2.3 (2), J3.4
LED1: LED2.A, R3.1
R1: BTN_R1.3 (2), J3.2
R2: BTN_R2.3 (2), J3.3
SWITCH_OUT+: J3.6, R3.2

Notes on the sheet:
D-PAD BUTTONS
FACE BUTTONS
SHOULDER BUTTONS
FUNCTION BUTTONS
POWER
BATTERY
SWITCH
FRONTBOARD LED
DISPLAY
RASPBERRY PI
BACKBOARD LED
SEE TOP BOARD FOR DETAILS

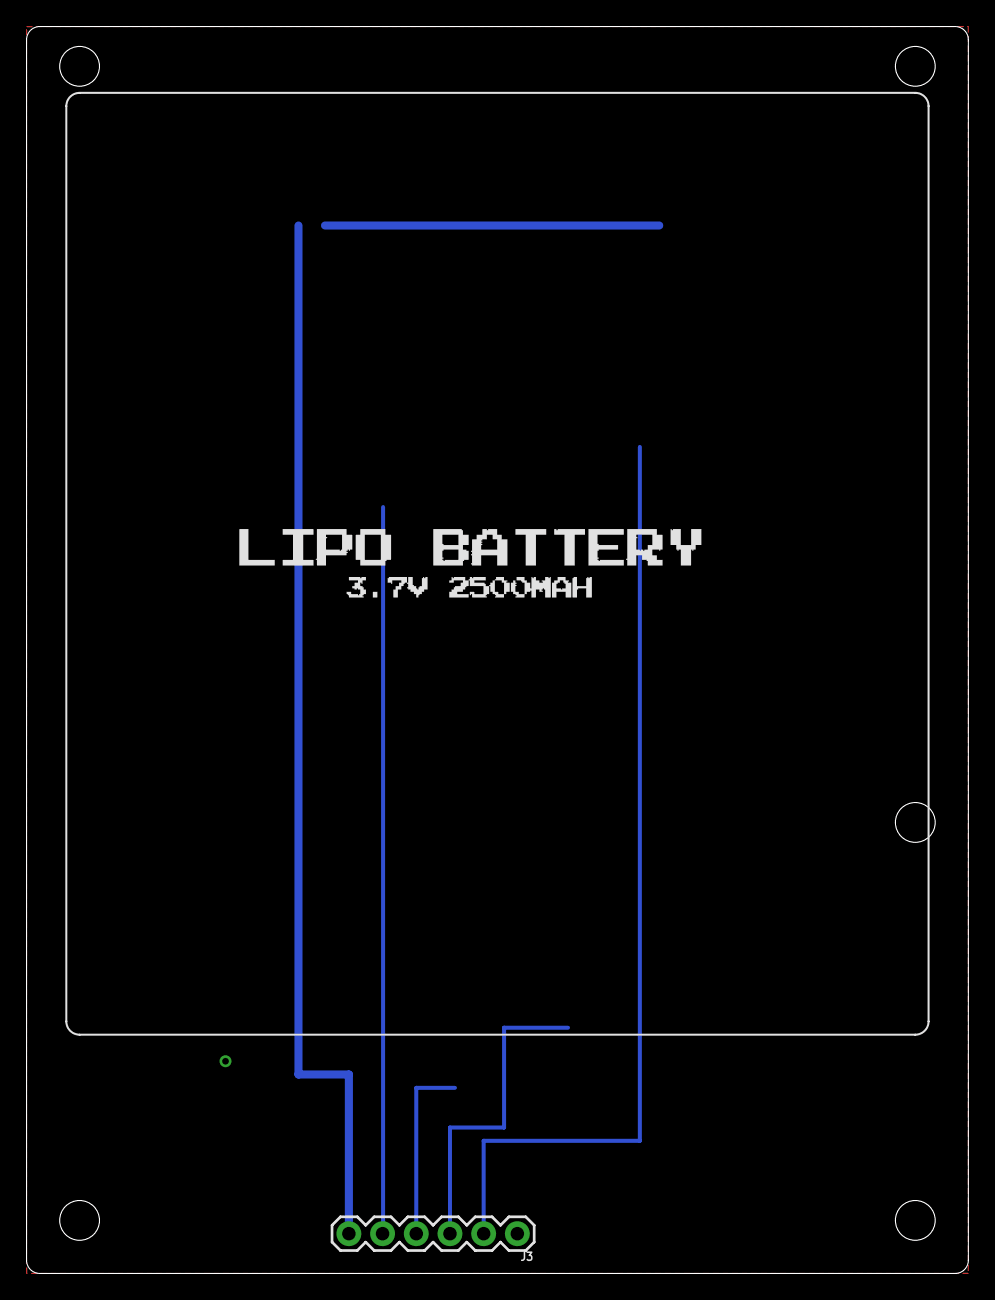
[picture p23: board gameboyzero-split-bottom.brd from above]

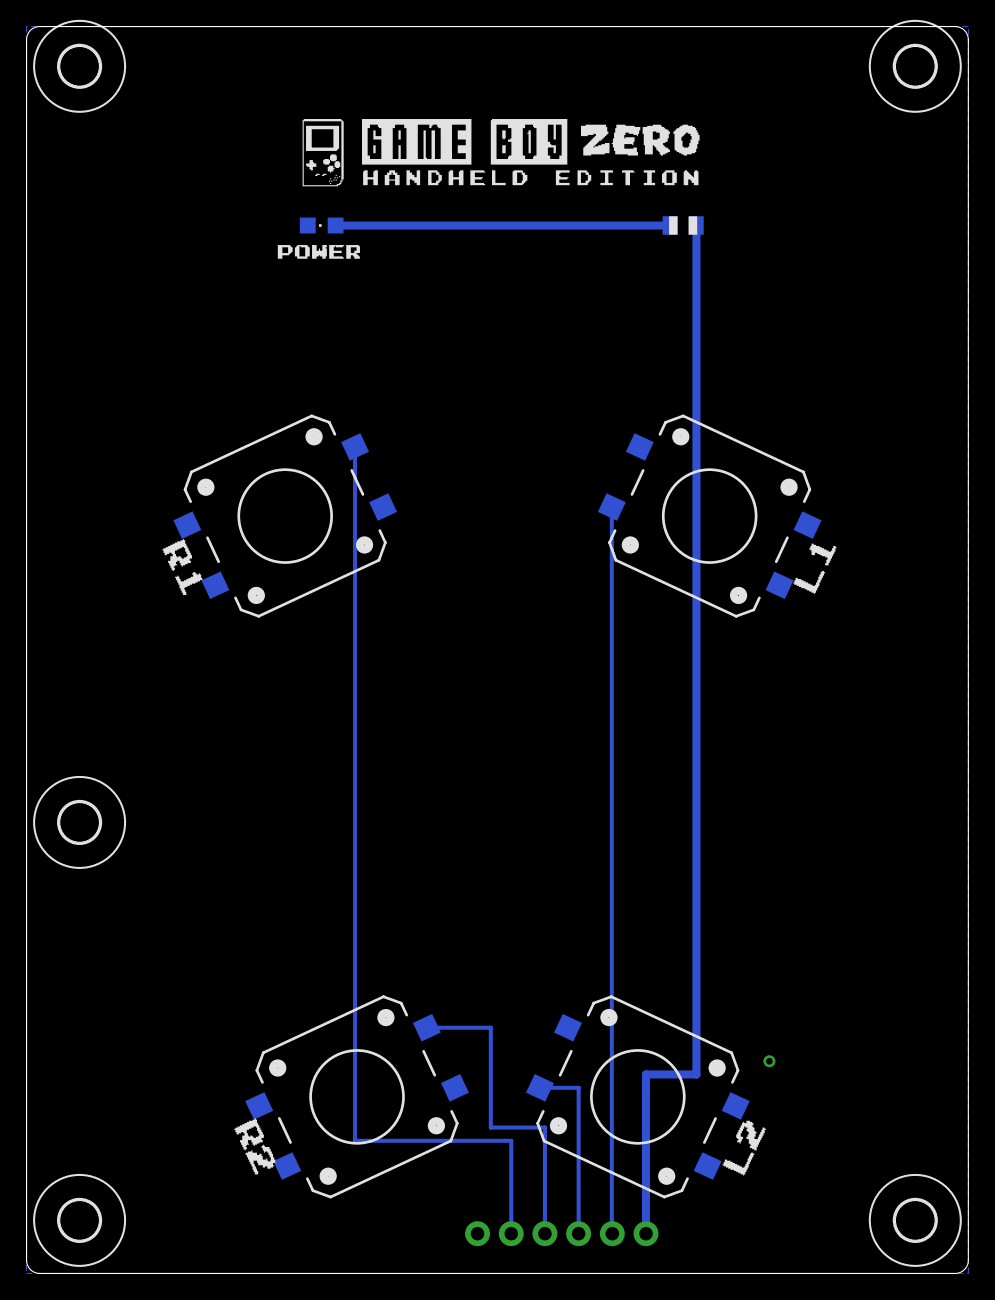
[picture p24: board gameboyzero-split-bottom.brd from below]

Board: 2 copper layers, 71.0 x 94.0 mm, 12 parts (11 on the bottom side), 7 nets.

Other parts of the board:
H6, H7, H8, H9, H10: MOUNT-HOLE2.8; 3,0

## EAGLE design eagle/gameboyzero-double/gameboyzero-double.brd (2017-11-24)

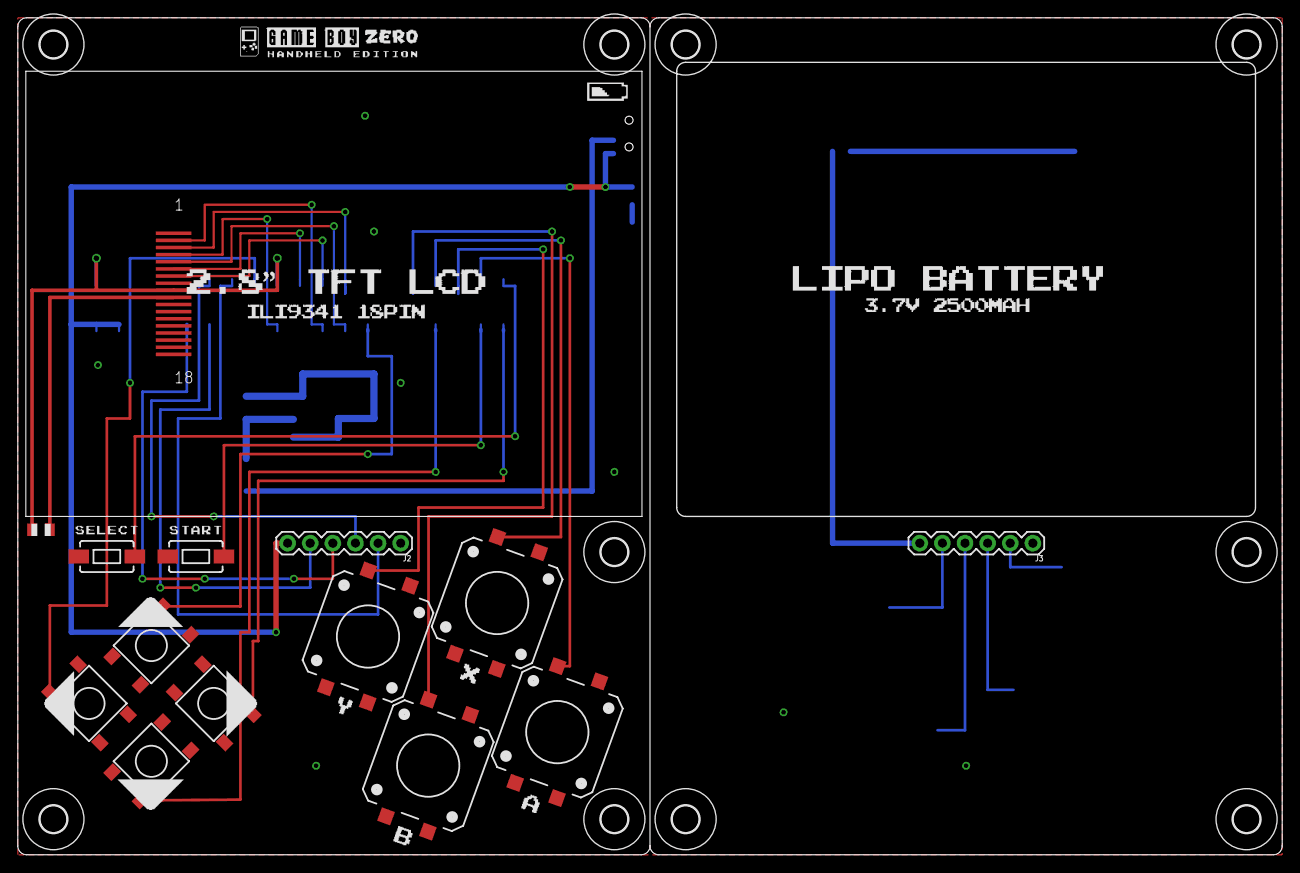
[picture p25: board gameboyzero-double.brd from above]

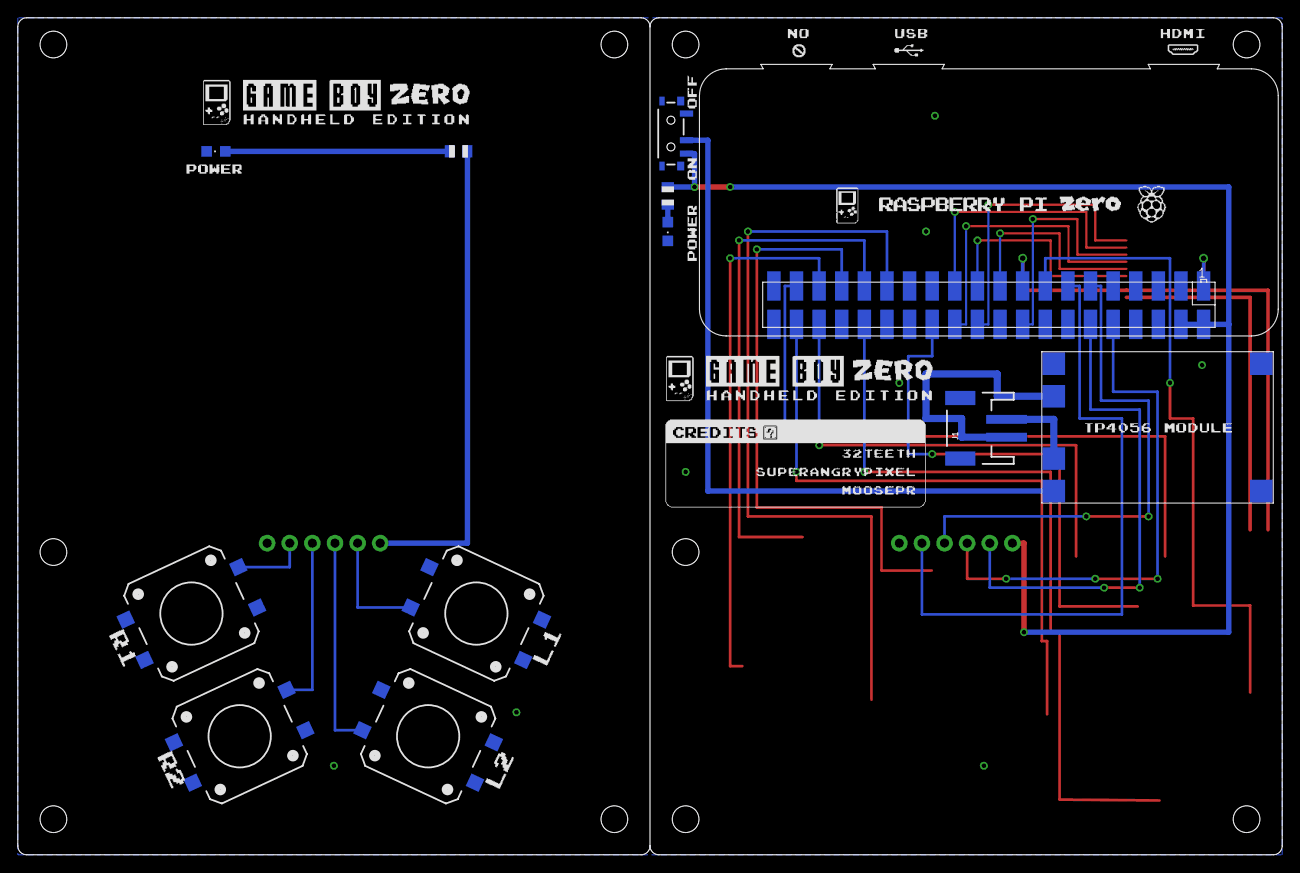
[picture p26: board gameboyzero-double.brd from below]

Board: 2 copper layers, 142.0 x 94.0 mm, 36 parts (12 on the bottom side), 29 nets.

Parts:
BTN_A: MOMENTARY-SWITCH-SPST-SMD-12MM; TACTILE_SWITCH_SMD_12MM
BTN_B: MOMENTARY-SWITCH-SPST-SMD-12MM; TACTILE_SWITCH_SMD_12MM
BTN_DOWN: MOMENTARY-SWITCH-SPST-SMD-6.2MM-TALL; TACTILE_SWITCH_SMD_6.2MM_TALL
BTN_L1, BTN_L2: MOMENTARY-SWITCH-SPST-SMD-12MM; TACTILE_SWITCH_SMD_12MM
BTN_LEFT: MOMENTARY-SWITCH-SPST-SMD-6.2MM-TALL; TACTILE_SWITCH_SMD_6.2MM_TALL
BTN_R1, BTN_R2: MOMENTARY-SWITCH-SPST-SMD-12MM; TACTILE_SWITCH_SMD_12MM
BTN_RIGHT: MOMENTARY-SWITCH-SPST-SMD-6.2MM-TALL; TACTILE_SWITCH_SMD_6.2MM_TALL
BTN_SELECT: MOMENTARY-SWITCH-SPST-SMD-6.0X3.5MM; TACTILE_SWITCH_SMD_6.0X3.5MM
BTN_START: MOMENTARY-SWITCH-SPST-SMD-6.0X3.5MM; TACTILE_SWITCH_SMD_6.0X3.5MM
BTN_UP: MOMENTARY-SWITCH-SPST-SMD-6.2MM-TALL; TACTILE_SWITCH_SMD_6.2MM_TALL
BTN_X: MOMENTARY-SWITCH-SPST-SMD-12MM; TACTILE_SWITCH_SMD_12MM
BTN_Y: MOMENTARY-SWITCH-SPST-SMD-12MM; TACTILE_SWITCH_SMD_12MM
H1: MOUNT-HOLE3.0; 3,0
H2, H3, H4, H5, H6, H7, H8, H9, H10: MOUNT-HOLE2.8; 3,0
J1: JST-2-SMD
J2, J3: 1X06
LED1, LED2: CHIPLED_0805
PI1: RPI-ZERO; RASPBERRYPI_BASTELSTUBE_V13_RASPI_BOARD_B+_FULL
POWER1: 03962A
R1: 3R9; R0805
R2, R3: 1K; R0805
S2: SWITCH_SPST_SMD_A
SCREEN1: GAMEBOYZEROHANDHELDDISPLAYS-2.8

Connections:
3V3: PI1.1, PI1.17, R1.2, SCREEN1.P$9
3V3100OHM: R1.1, SCREEN1.P$10
A: BTN_A.3, PI1.35
B: BTN_B.3, PI1.29
BATT+: J1.2, POWER1.B+
BATT-: J1.1, POWER1.B-
CSX: PI1.24, SCREEN1.P$5
D/CX: PI1.18, SCREEN1.P$4
DOWN: BTN_DOWN.B2, PI1.32
GND: BTN_A.1, BTN_B.1, BTN_DOWN.A2, BTN_L1.1, BTN_L2.1, BTN_LEFT.A2, BTN_R1.1, BTN_R2.1, BTN_RIGHT.A2, BTN_SELECT.1, BTN_START.1, BTN_UP.A2, BTN_X.1, BTN_Y.1, J2.1, J3.1, LED1.C, LED2.C, PI1.6, PI1.9, PI1.14, PI1.20, PI1.25, PI1.30, PI1.34, PI1.39, POWER1.OUT-, SCREEN1.P$1, SCREEN1.P$8, SCREEN1.P$11, SCREEN1.P$12, SCREEN1.P$13, SCREEN1.P$14
L1: BTN_L1.3, J2.5, J3.5, PI1.12
L2: BTN_L2.3, J2.4, J3.4, PI1.10
LED: LED1.A, R2.1
LED1: LED2.A, R3.1
LEFT: BTN_LEFT.B2, PI1.15
R1: BTN_R1.3, J2.2, J3.2, PI1.13
R2: BTN_R2.3, J2.3, J3.3, PI1.11
RESET: PI1.22, SCREEN1.P$2
RIGHT: BTN_RIGHT.B2, PI1.38
SCL: PI1.23, SCREEN1.P$3
SDI: PI1.19, SCREEN1.P$6
SDO: PI1.21, SCREEN1.P$7
SELECT: BTN_SELECT.2, PI1.37
START: BTN_START.2, PI1.36
SWITCH_IN+: POWER1.OUT+, S2.2
SWITCH_OUT+: J2.6, J3.6, PI1.2, PI1.4, R2.2, R3.2, S2.1
UP: BTN_UP.B2, PI1.26
X: BTN_X.3, PI1.31
Y: BTN_Y.3, PI1.33

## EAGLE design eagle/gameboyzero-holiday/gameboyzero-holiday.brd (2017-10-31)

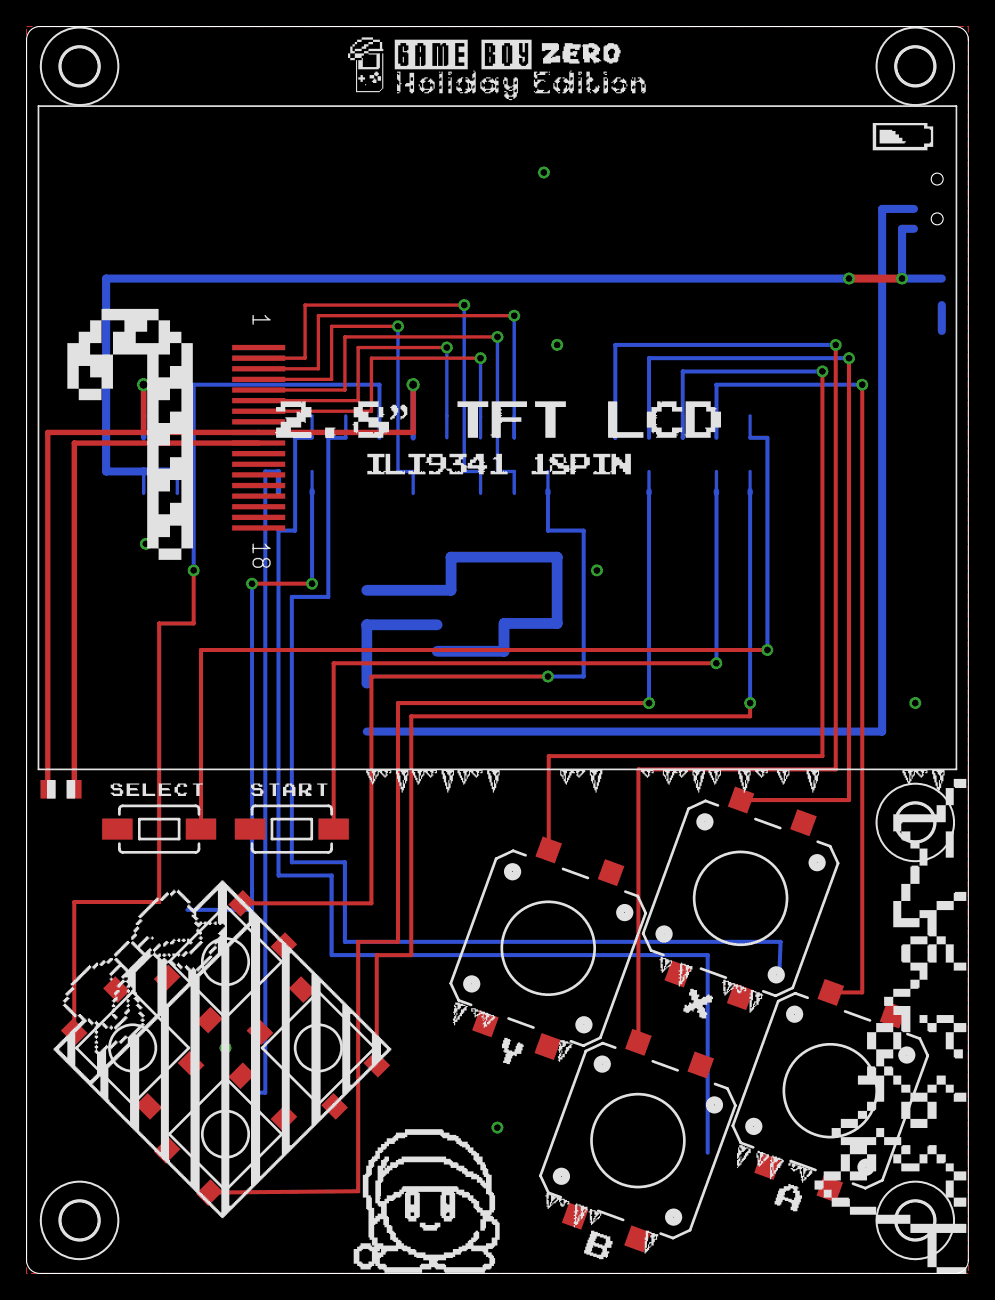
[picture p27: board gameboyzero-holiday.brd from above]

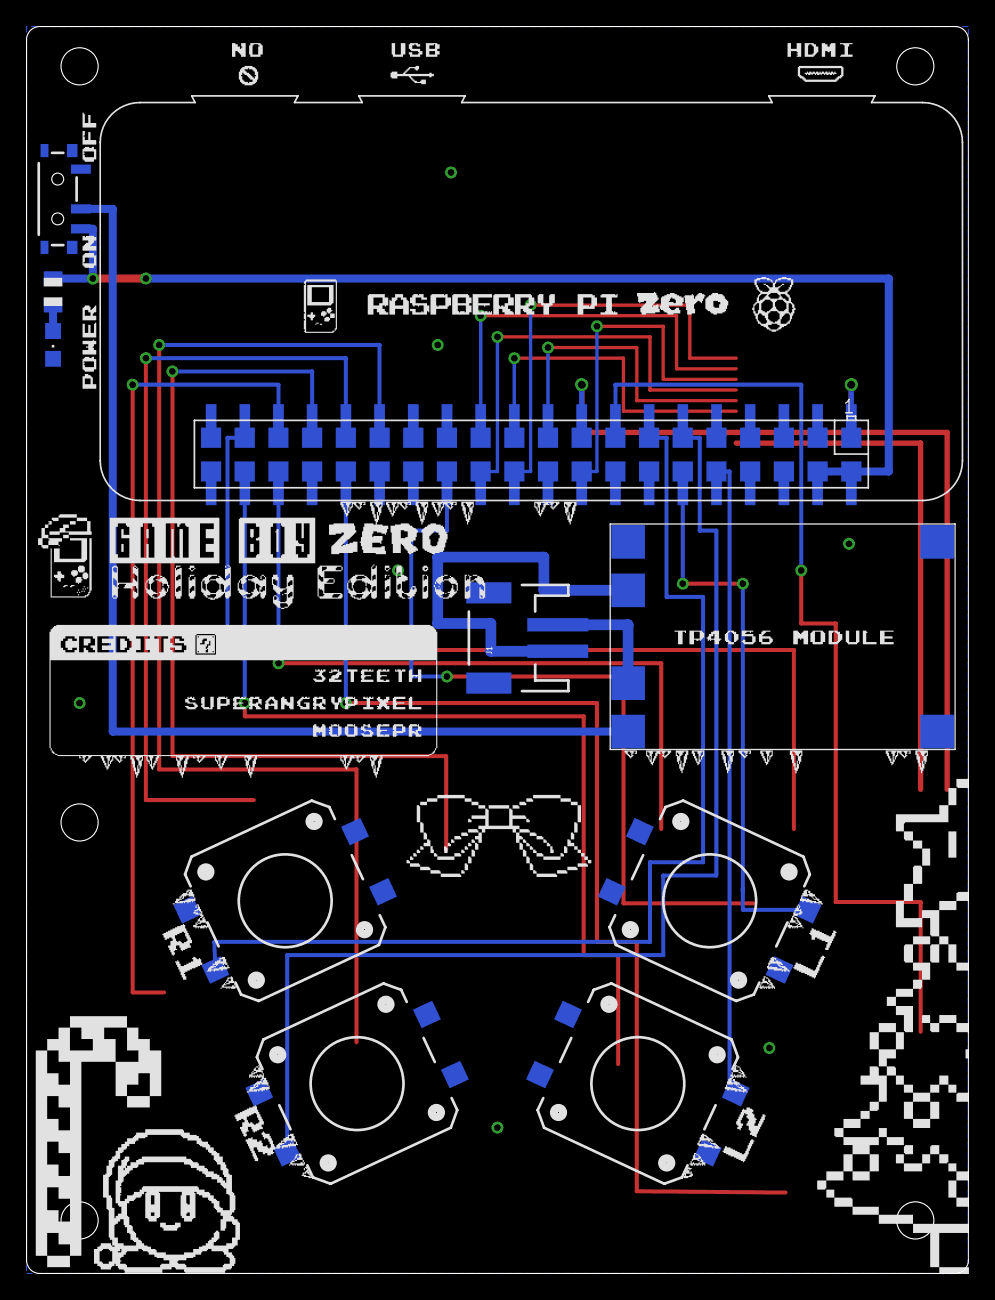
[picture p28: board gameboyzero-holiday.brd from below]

Board: 2 copper layers, 71.0 x 94.0 mm, 27 parts (10 on the bottom side), 28 nets.

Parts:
BTN_A: MOMENTARY-SWITCH-SPST-SMD-12MM; TACTILE_SWITCH_SMD_12MM
BTN_B: MOMENTARY-SWITCH-SPST-SMD-12MM; TACTILE_SWITCH_SMD_12MM
BTN_DOWN: MOMENTARY-SWITCH-SPST-SMD-6.2MM-TALL; TACTILE_SWITCH_SMD_6.2MM_TALL
BTN_L1, BTN_L2: MOMENTARY-SWITCH-SPST-SMD-12MM; TACTILE_SWITCH_SMD_12MM
BTN_LEFT: MOMENTARY-SWITCH-SPST-SMD-6.2MM-TALL; TACTILE_SWITCH_SMD_6.2MM_TALL
BTN_R1, BTN_R2: MOMENTARY-SWITCH-SPST-SMD-12MM; TACTILE_SWITCH_SMD_12MM
BTN_RIGHT: MOMENTARY-SWITCH-SPST-SMD-6.2MM-TALL; TACTILE_SWITCH_SMD_6.2MM_TALL
BTN_SELECT: MOMENTARY-SWITCH-SPST-SMD-6.0X3.5MM; TACTILE_SWITCH_SMD_6.0X3.5MM
BTN_START: MOMENTARY-SWITCH-SPST-SMD-6.0X3.5MM; TACTILE_SWITCH_SMD_6.0X3.5MM
BTN_UP: MOMENTARY-SWITCH-SPST-SMD-6.2MM-TALL; TACTILE_SWITCH_SMD_6.2MM_TALL
BTN_X: MOMENTARY-SWITCH-SPST-SMD-12MM; TACTILE_SWITCH_SMD_12MM
BTN_Y: MOMENTARY-SWITCH-SPST-SMD-12MM; TACTILE_SWITCH_SMD_12MM
H1, H2, H3, H4, H5: MOUNT-HOLE2.8; 2,8
J1: JST-2-SMD
LED1: CHIPLED_0805
PI1: RPI-ZERO; RASPBERRYPI_BASTELSTUBE_V13_RASPI_BOARD_B+_FULL
POWER1: 03962A
R1: 3R9; R0805
R2: 100; R0805
S2: SWITCH_SPST_SMD_A
SCREEN1: GAMEBOYZEROHANDHELDDISPLAYS-2.8

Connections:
3V3: PI1.1, PI1.17, PI1.41, PI1.57, R1.2, SCREEN1.P$9
3V3100OHM: R1.1, SCREEN1.P$10
A: BTN_A.3, PI1.35, PI1.75
B: BTN_B.3, PI1.29, PI1.69
BATT+: J1.2, POWER1.B+
BATT-: J1.1, POWER1.B-
CSX: PI1.24, PI1.64, SCREEN1.P$5
D/CX: PI1.18, PI1.58, SCREEN1.P$4
DOWN: BTN_DOWN.B2, PI1.32, PI1.72
GND: BTN_A.1, BTN_B.1, BTN_DOWN.A2, BTN_L1.1, BTN_L2.1, BTN_LEFT.A2, BTN_R1.1, BTN_R2.1, BTN_RIGHT.A2, BTN_SELECT.1, BTN_START.1, BTN_UP.A2, BTN_X.1, BTN_Y.1, LED1.C, PI1.6, PI1.9, PI1.14, PI1.20, PI1.25, PI1.30, PI1.34, PI1.39, PI1.46, PI1.49, PI1.54, PI1.60, PI1.65, PI1.70, PI1.74, PI1.79, POWER1.OUT-, SCREEN1.P$1, SCREEN1.P$8, SCREEN1.P$11, SCREEN1.P$12, SCREEN1.P$13, SCREEN1.P$14
L1: BTN_L1.3, PI1.12, PI1.52
L2: BTN_L2.3, PI1.10, PI1.50
LED: LED1.A, R2.1
LEFT: BTN_LEFT.B2, PI1.15, PI1.55
R1: BTN_R1.3, PI1.13, PI1.53
R2: BTN_R2.3, PI1.11, PI1.51
RESET: PI1.22, PI1.62, SCREEN1.P$2
RIGHT: BTN_RIGHT.B2, PI1.38, PI1.78
SCL: PI1.23, PI1.63, SCREEN1.P$3
SDI: PI1.19, PI1.59, SCREEN1.P$6
SDO: PI1.21, PI1.61, SCREEN1.P$7
SELECT: BTN_SELECT.2, PI1.37, PI1.77
START: BTN_START.2, PI1.36, PI1.76
SWITCH_IN+: POWER1.OUT+, S2.2
SWITCH_OUT+: PI1.2, PI1.4, PI1.42, PI1.44, R2.2, S2.1
UP: BTN_UP.B2, PI1.26, PI1.66
X: BTN_X.3, PI1.31, PI1.71
Y: BTN_Y.3, PI1.33, PI1.73

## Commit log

2017-10-10 Inital commit post KickStarter launch
    [gameboyzero.brd, gameboyzero.sch]
2017-10-10 Updated Case Directory
2017-10-10 Updated BOM Directory
    [gameboyzero.csv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]
2017-10-10 Removed Copyrights and Trademarks
    [gameboyzero.GBL, gameboyzero.GBO, gameboyzero.GBP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]
2017-10-11 New Silk and New Case files
    [gameboyzero-case.brd, gameboyzero-case.dxf, gameboyzero.brd]
2017-10-11 Wed 11 Oct 2017 16:52:53 EDT
    [gameboyzero-case.brd, gameboyzero-case.dxf]
2017-10-12 Thu 12 Oct 2017 11:18:29 EDT
    [gameboyzero-keychain.GBL, gameboyzero-keychain.GBO, gameboyzero-keychain.GBP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]
2017-10-13 Fri 13 Oct 2017 16:15:10 EDT
    [gameboyzero.brd, gameboyzero.csv, gameboyzero.sch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]
2017-10-17 Tue 17 Oct 2017 18:00:43 EDT updated gerbers
    [gameboyzero-nolinks.csv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]
2017-10-18 Wed 18 Oct 2017 19:37:03 EDT updated gerbers
    [gameboyzero-holiday.brd, gameboyzero-holiday.sch, gameboyzero.brd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]
2017-10-19 Thu 19 Oct 2017 10:10:47 EDT - holiday express board released
    [gameboyzero-holiday.GBL, gameboyzero-holiday.GBO, gameboyzero-holiday.GBP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]
2017-10-19 Thu 19 Oct 2017 10:17:15 EDT - holiday express board released
2017-10-23 Mon 23 Oct 2017 13:27:00 EDT - holiday express board released
    [gameboyzero-holiday.sch, gameboyzero-tft.brd, gameboyzero-tft.sch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]
2017-10-25 Wed 25 Oct 2017 09:07:01 EDT - holiday express board released
    [gameboyzero-holiday.brd, gameboyzero-holiday.sch, gameboyzero.brd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]
2017-10-25 Wed 25 Oct 2017 09:57:53 EDT - holiday express board released
    [gameboyzero.csv]
2017-10-26 Thu 26 Oct 2017 08:34:56 EDT - holiday express board released
    [gameboyzero.csv]
2017-10-27 Fri 27 Oct 2017 10:05:30 EDT - holiday express board released
2017-10-30 Mon 30 Oct 2017 11:48:34 EDT - new case
    [gameboyzero-case.dxf, gameboyzero.brd, gameboyzero.dxf]
2017-10-30 Mon 30 Oct 2017 18:03:52 EDT - new case
    [gameboyzero.dxf]
2017-10-31 last minute fixes before production
    [gameboyzero-holiday.brd, gameboyzero-holiday.sch, gameboyzero.brd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]
2017-10-31 Tue 31 Oct 2017 16:24:41 EDT
    [gameboyzero.brd, gameboyzero.dxf]
2017-11-07 Tue 7 Nov 2017 15:07:46 EST
    [gameboyzero-new.brd]
2017-11-07 Tue 7 Nov 2017 15:28:11 EST
    [gameboyzero-new.brd, gameboyzero-original.brd, gameboyzero-original.dxf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]
2017-11-07 Tue 7 Nov 2017 15:29:14 EST
    [gameboyzero.brd]
2017-11-08 Tue Nov 7 23:54:05 EST 2017
    [gameboyzero.brd]
2017-11-08 Tue Nov 7 23:58:46 EST 2017
    [gameboyzero.brd]
2017-11-08 Wed 8 Nov 2017 12:24:01 EST
    [gameboyzero-original.dxf, gameboyzero.brd, gameboyzero.dxf]
2017-11-08 Wed 8 Nov 2017 16:26:35 EST
    [gameboyzero-blue.dxf]
2017-11-14 Tue 14 Nov 2017 17:21:10 EST
    [gameboyzero.GBL, gameboyzero.GBO, gameboyzero.GBP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]
2017-11-21 Mon 20 Nov 2017 21:17:25 EST
    [gameboyzero-landscape.brd, gameboyzero-landscape.sch, gameboyzero.brd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]
2017-11-21 Mon 20 Nov 2017 21:21:54 EST
    [gameboyzero-landscape.brd, gameboyzero-landscape.sch]
2017-11-24 Fri 24 Nov 2017 17:05:07 EST
    [gameboyzero-blue.dxf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]
2017-11-27 Mon 27 Nov 2017 11:39:46 EST
    [gameboyzero-double.GBL, gameboyzero-double.GBO, gameboyzero-double.GBP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]
2017-11-28 Tue 28 Nov 2017 18:37:52 EST
    [gameboyzero-split-board.brd, gameboyzero-split-board.dxf, gameboyzero-split-board.skp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]
2017-12-01 Fri 1 Dec 2017 08:32:23 CST
    [gameboyzero-split-bottom.csv, gameboyzero-split-top.brd, gameboyzero-split-top.csv]
2017-12-06 Wed 6 Dec 2017 14:49:20 EST
    [_gameboyzero-split.brd, _gameboyzero-split.sch, gameboyzero-split-bottom.brd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]
2017-12-11 Mon 11 Dec 2017 15:37:02 EST
    [gameboyzero-split-bottom.GBL, gameboyzero-split-bottom.GBO, gameboyzero-split-bottom.GBP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]
2017-12-12 Tue 12 Dec 2017 14:39:35 EST - edited retrogame.cfg with RIGHTSHIFT for Select button
2017-12-17 Sun 17 Dec 2017 11:46:54 EST - edited retrogame.cfg with RIGHTSHIFT for Select button
2018-01-02 Tue 2 Jan 2018 16:26:20 EST
    [_gameboyzero-split.brd, _gameboyzero-split.sch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]
2018-01-03 Wed 3 Jan 2018 12:40:18 EST
    [gameboyzero-split-board.skp, gameboyzero-split-board~.skp]
2018-01-03 Wed 3 Jan 2018 12:56:02 EST
    [gameboyzero-split-board~.skp]
2018-01-03 added gerbers
2018-01-12 Fri 12 Jan 2018 17:10:25 EST
    [gameboyzero-split-board.brd, gameboyzero-split-top.sch]
2018-01-25 simplified plexi
    [gameboyzero-split-board.brd, gameboyzero-split-board.dxf]
2018-02-14 Wed 14 Feb 2018 12:34:53 EST
    [gameboyzero-split-board-10.dxf, gameboyzero-split-board-single.brd, gameboyzero-split-board-single.dxf]
2018-02-22 Thu 22 Feb 2018 09:08:23 EST
    [gameboyzero-split-board-10.dxf, gameboyzero-split-board-single.brd, gameboyzero-split-board-single.dxf]
2018-03-05 Mon 5 Mar 2018 14:09:31 EST
    [gameboyzero-split-top.dxf]

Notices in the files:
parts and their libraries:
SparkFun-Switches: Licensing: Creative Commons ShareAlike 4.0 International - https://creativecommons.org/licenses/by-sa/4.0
